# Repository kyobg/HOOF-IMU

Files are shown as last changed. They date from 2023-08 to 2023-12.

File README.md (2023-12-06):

# Hoof-IMU Motion Analysis - Senior Design Project

**Preface:** Here are a couple links to help familiarize yourself with Git and GitHub.

Links: 

(1) How to use Git click [here](https://youtu.be/USjZcfj8yxE?si=m7MtrsjsvbkFWDZs)  

(2) How to use GitHub click [here](https://www.youtube.com/watch?v=nhNq2kIvi9s&ab_channel=ColtSteele)

## Terminology:

**IMU** - Inertial Measurement Unit

**DOF** - Degrees of Freedom

**Laminitis** - The inflammation of the laminae of the foot, which results in extreme pain and instability in horses.

## Project Synopsis:
A custom 9-DOF IMU with an additional 3-axis high-g accelerometer, which is used for impulses where the low-g accelerometer may clip, will be used to detect laminitis or rotational hoof sickness, in racehorses.
The IMUs come equipped with a 3-axis low-g accelerometer, 3-axis high-g accelerometer, 3-axis gyroscope, and 3-axis magnetometer. Additionally, circuitry will be added for other features like GPS, Real-time timekeeping, and power management.

The IMUs will communicate directly to a central hub through a BLE mesh, which will allow wireless transmission of recorded data from each unique IMU device. After data collection, the data will be read from the central into a serial port on a computer where it will save the data and provide a real-time plot for data processing later.

## Goals:
- [x]  Test with mobile battery pack                                                      
- [x]  Add Timestamp to periphal data packet                                              
- [x]  Distance/Reliablility measurement                                                  ~40 ft
- [x]  Complete power management system                                                   
- [x]  Complete real-time plotting using BetterSerialMonitor                              
- [ ]  Integrate GPS into the IMU system                                                  No Longer Feasbile due to Time Constraints
- [ ]  Complete PCB design with integrated circuits and order appropriate chips           Future Goal

## Current Repository Maintainer and Authors
Kyle G:
- [GitHub](https://github.com/kyobg)
- [LinkedIn](https://www.linkedin.com/in/kyle-b-garcia/)

Kevin B:
- [GitHub](https://github.com/kevinbrannan)
- [LinkedIn](https://www.linkedin.com/in/kevin-brannan-885446233/)

Elena M:
- [GitHub](https://github.com/evolutis101)
- [LinkedIn](https://www.linkedin.com/in/elenammontalvo/)

Jonathan H:
- [GitHub](https://github.com/Grlee316)
- [LinkedIn](https://www.linkedin.com/in/jhanbali/)

## Future Repository Maintainer
Josue D:
- [Github](https://github.com/Jdiazcaminos)
- [LinkedIn](https://www.linkedin.com/in/josuediaz-caminos/)

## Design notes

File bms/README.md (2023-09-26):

# Battery Management system
Battery Management System is a critical component in modern battery-powered systems, playing a vital role in maximizing battery lifespan, performance, and safety while also enabling efficient energy management.
## Important factors to consider for BMS 
- Voltage Monitoring
- Current Monitoring
- Temperature Monitoring
- Cell Balancing
- State of Charge (SOC) Estimation
- State of Health (SOH) Estimation
- Overcurrent and Overvoltage Protection
- Cell Protection

## Proportional Integral Derivative (PID)
PID of battery

## Battery we are using 
*Voltage = 3.7 v 
*capacity = 650mAh 
*capacity = 1500mAh
An individual LiPo cell has a nominal voltage of 3.7V. When fully charged you will see nearly 4.3V on the cell but it will quickly drop to 3.7V under normal use. When depleted, the cell will be around 3V. This means your project will need to handle various voltages if you are running directly from a cell.
voltage chart

## Theoretical components 


## Monitoring test  ( using SparkFun battery babysitter) 




## Monitoring test 2 ( using IN219) 
Measure_PCV_IN219

## Resource

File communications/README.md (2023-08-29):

# Communications

This folder contains the code of both the peripheral/server devices and the central/client device.

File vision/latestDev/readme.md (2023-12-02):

This folder will contain the latest development of this vision projects

Current MATLAB Project file is [latest](../../vision/latestDev/horse_test3.m)

Current Masking file is: [mask](../../vision/latestDev/createMask6.m)

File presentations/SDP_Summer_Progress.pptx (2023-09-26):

## Hoof IMU

By
Elena Montalvo
Jonathan Hanbali
Josue Diaz
Kevin Brannan
Kyle Garcia
Matthew Wagaman

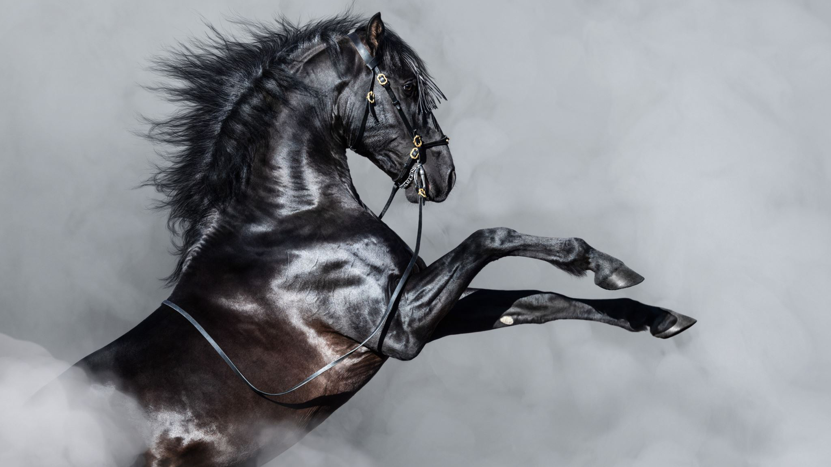
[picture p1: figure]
Black horse rearing in smoke

## Data Saving and Post Processing

- KST proved to not be capable of plotting the data in real-time using .csv files. As a result, BetterSerialPlotter is being used to plot data real-time, and is capable of exporting the results as a .csv file afterwards for post-processing.
- Alternatively, a Python script may be utilized for sorting data per device and exporting each to their own .csv file for individual device processing.

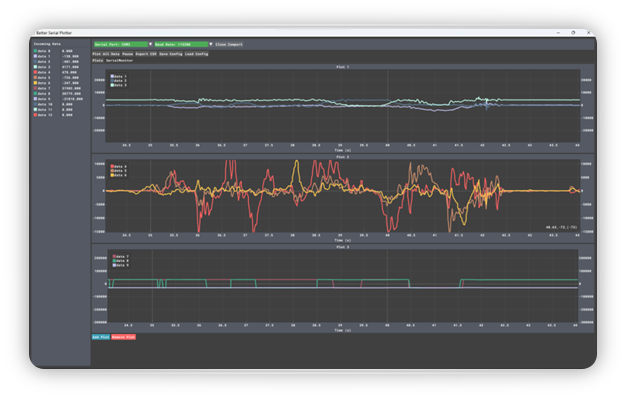
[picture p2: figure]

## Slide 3

Important factors to consider for BMS

Voltage Monitoring
Current Monitoring
Temperature Monitoring
Cell Balancing
State of Charge (SOC) Estimation
State of Health (SOH) Estimation
Overcurrent and Overvoltage Protection
Cell Protection

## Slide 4

Proportional Integral Derivative (PID)

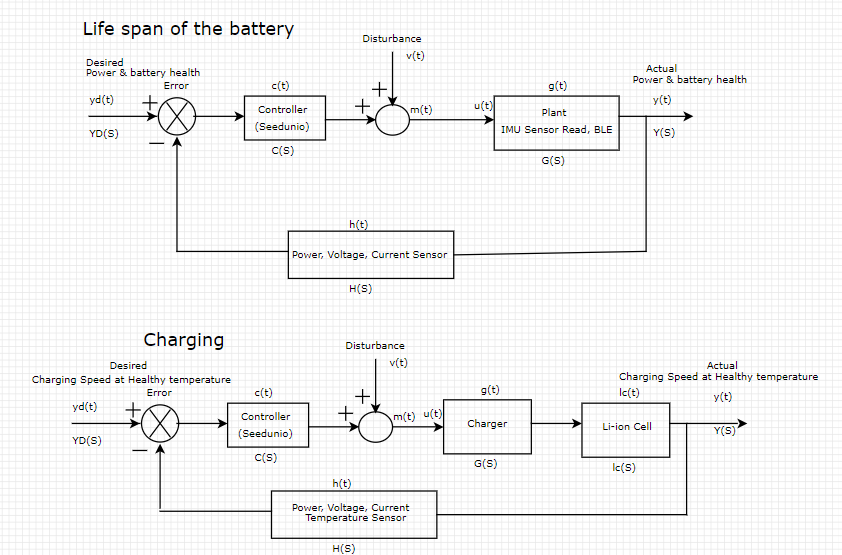
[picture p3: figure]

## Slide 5

BATERRY

Voltage = 3.7 v capacity = 650mAh capacity = 1500mAh An individual LiPo cell has a nominal voltage of 3.7V. When fully charged you will see nearly 4.3V on the cell but it will quickly drop to 3.7V under normal use. When depleted, the cell will be around 3V. This means your project will need to handle various voltages if you are running directly from a cell

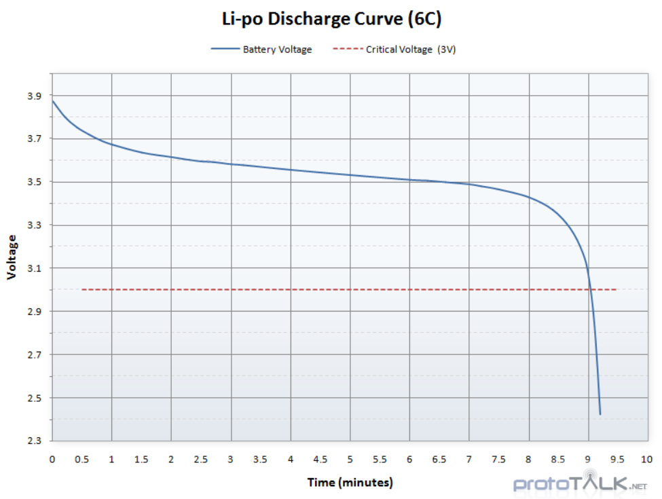
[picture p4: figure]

## Hardware to for BMS

- The Battery Babysitter features a pair of Texas Instruments LiPo-management ICs: a BQ24075 battery charger and a BQ27441-G1A fuel gauge.
- INA219 High Side DC Current Sensor Breakout - 26V ±3.2A Max - STEMMA QT

## Computer Vision

By using machine learning, we're aiming to create a skeletal body over a recorded video of the horse movement
Currently exploring options on using already build libraries and models to help us in detecting the skeleton and movements

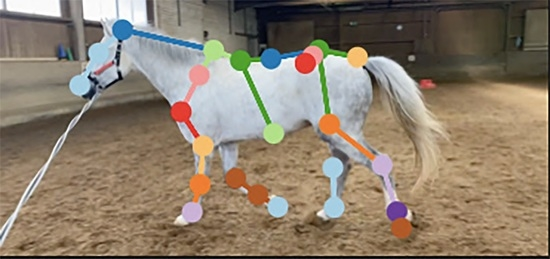
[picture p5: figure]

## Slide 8

Questions?

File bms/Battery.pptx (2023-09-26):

## BATTERY

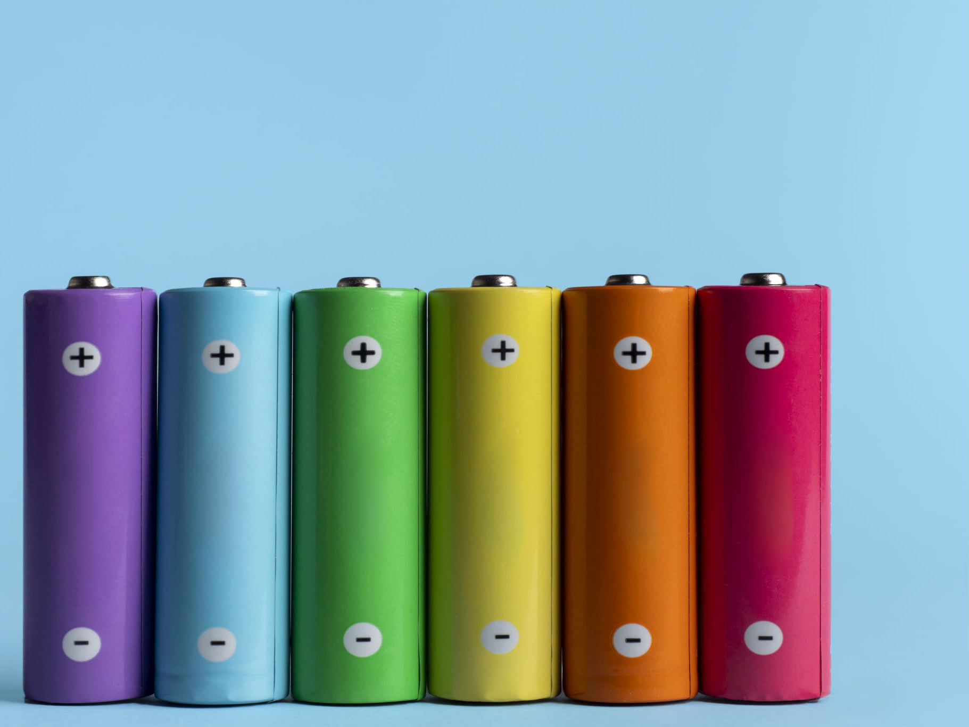
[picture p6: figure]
Multi-colour batteries

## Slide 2

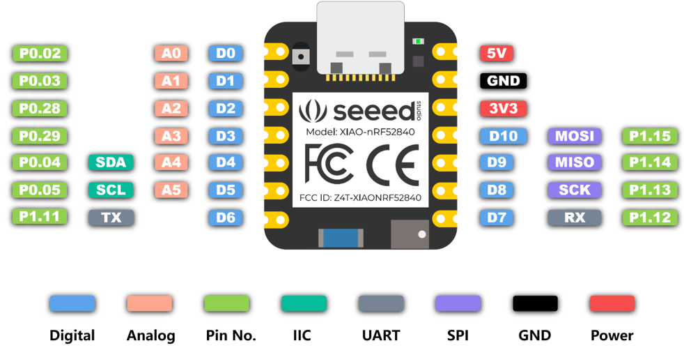
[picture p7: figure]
pir
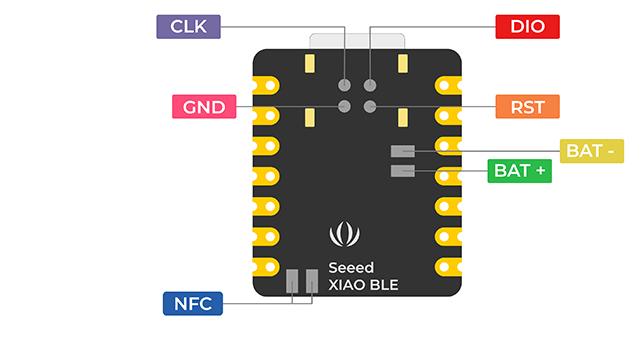
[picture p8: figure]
pir

## POWER MANAGEMENT UNIT (PMU)

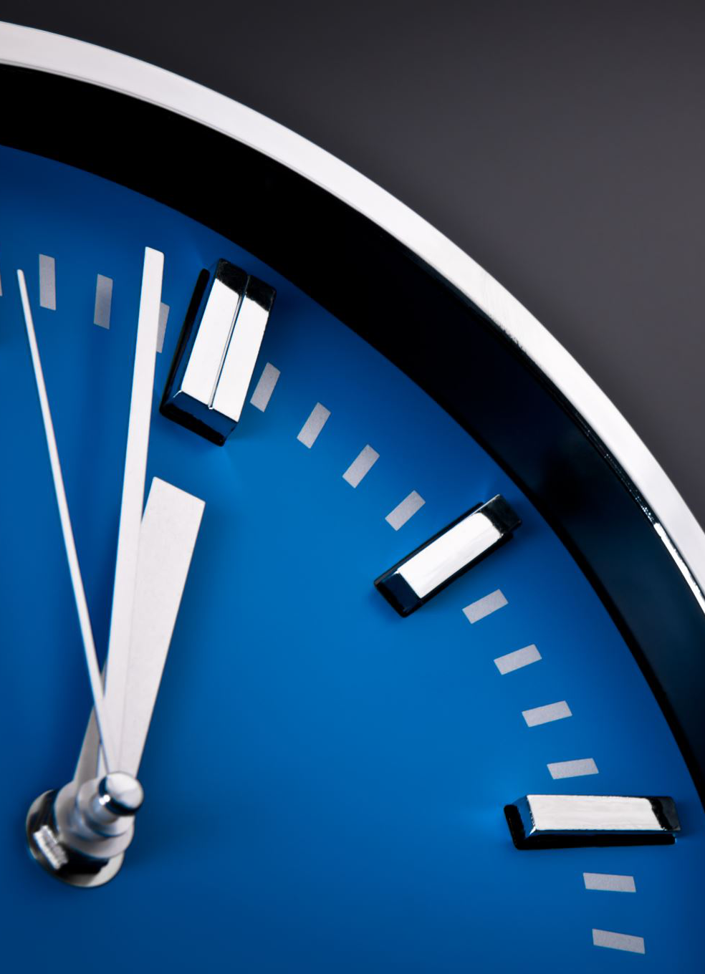
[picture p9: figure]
A blue wall clock showing the time 11:59

- The PMU automatically detects which power and clock resources are required by the different components in the system at any given time. It will then start/stop and choose operation modes in supply regulators and clock sources, without user interaction, to achieve the lowest power consumption possible.

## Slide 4

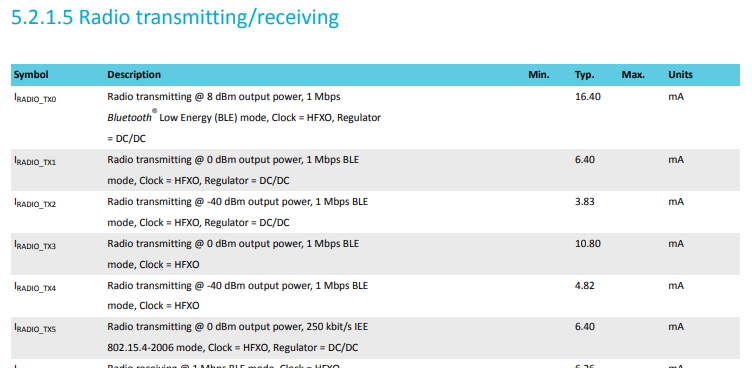
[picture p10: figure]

## POWER REQUIREMENT & CONSUMPTION

Seeed Studio XIAO nRF52840 (Sense) | | ISM330DHCX | MMC5983MA | MicroSD card breakout board+ | H3LIS331DL
Voltage | Current | Current | Current | Current | Current
3.3v | 50mA or 100mA | 1.5mA | 50mA or 100mA | 150mA | 7 μA

Total | ~351.5mA

## POWER REQUIREMENTS

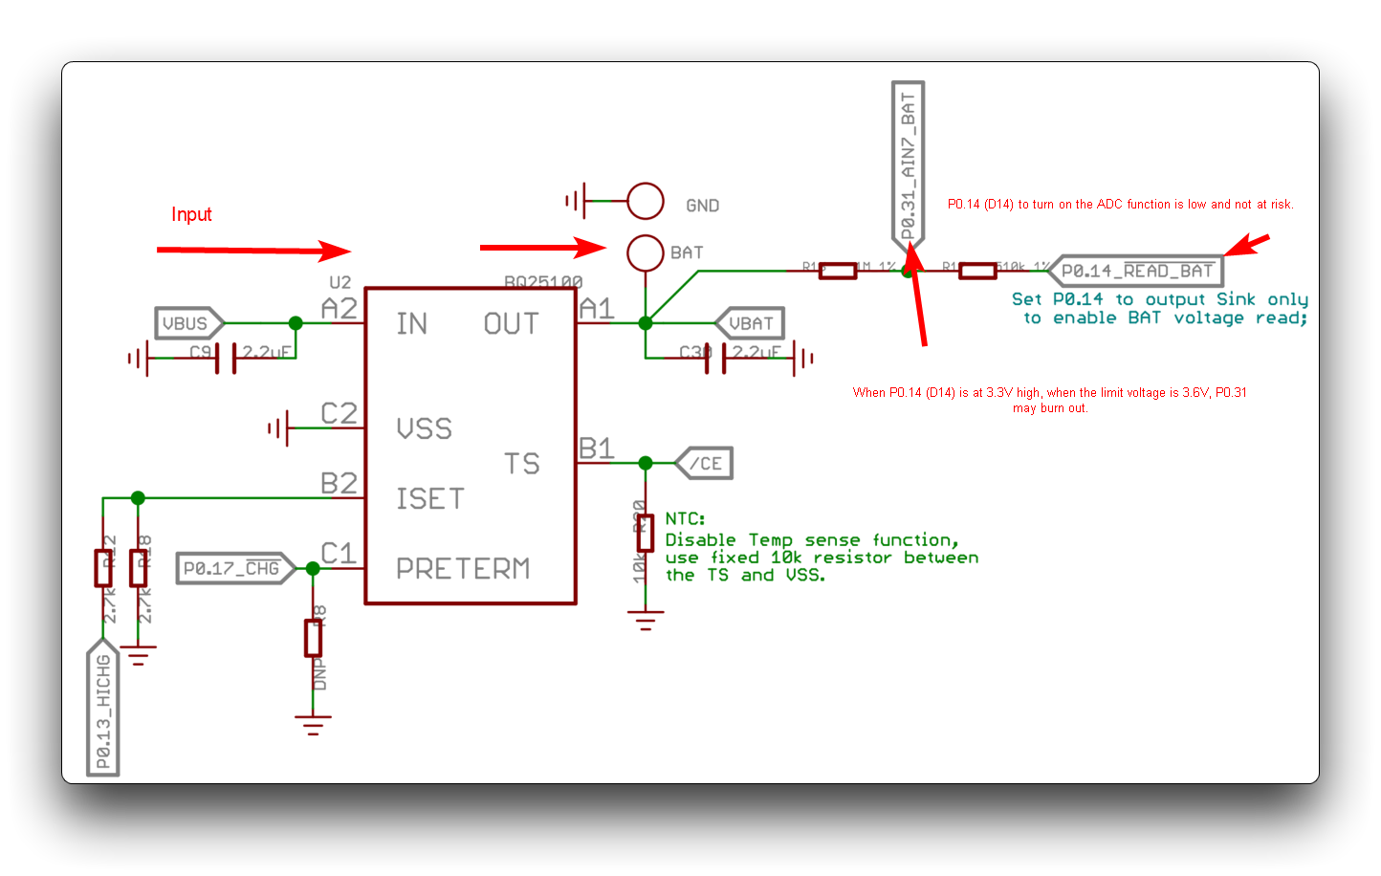
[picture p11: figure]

When P0.14 (D14) turns off the ADC function at a high level of 3.3V, P0.31 will be at the input voltage limit of 3.6V. There is a risk of burning out the P0.31 pin.

## Battery babysitter

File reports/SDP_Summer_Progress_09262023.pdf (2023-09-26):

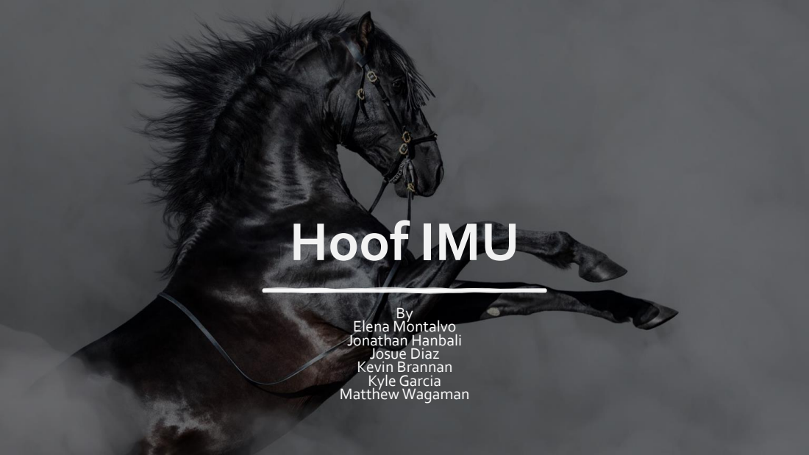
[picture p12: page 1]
Hoof IMU; By Elena Montalvo Jonathan Hanbali Josue Diaz Kevin Brannan Kyle Garcia Matthew Wagaman

# Data Saving and Post Processing

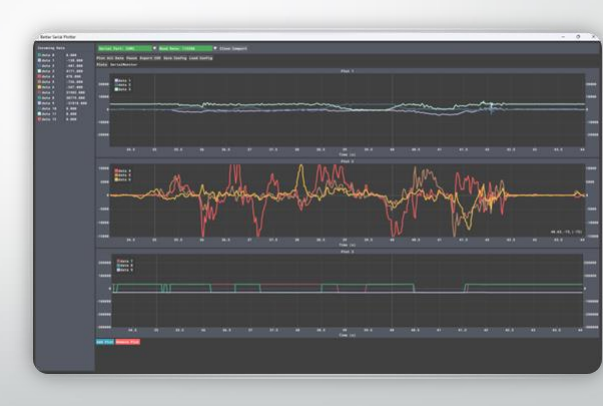
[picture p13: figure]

- KST proved to not be capable of plotting the data in real-time using .csv files. As a result, BetterSerialPlotter is being used to plot data real-time, and is capable
of exporting the results as a .csv
file afterwards for post-processing.
- Alternatively, a Python script may
be utilized for sorting data per device and exporting each to their own .csv file for individual device processing.

# IMPORTANT FACTORS TO CONSIDER FOR BMS

Voltage Monitoring

Current Monitoring

Temperature Monitoring

Cell Balancing

State of Charge (SOC) Estimation

State of Health (SOH) Estimation

Overcurrent and Overvoltage Protection

Cell Protection

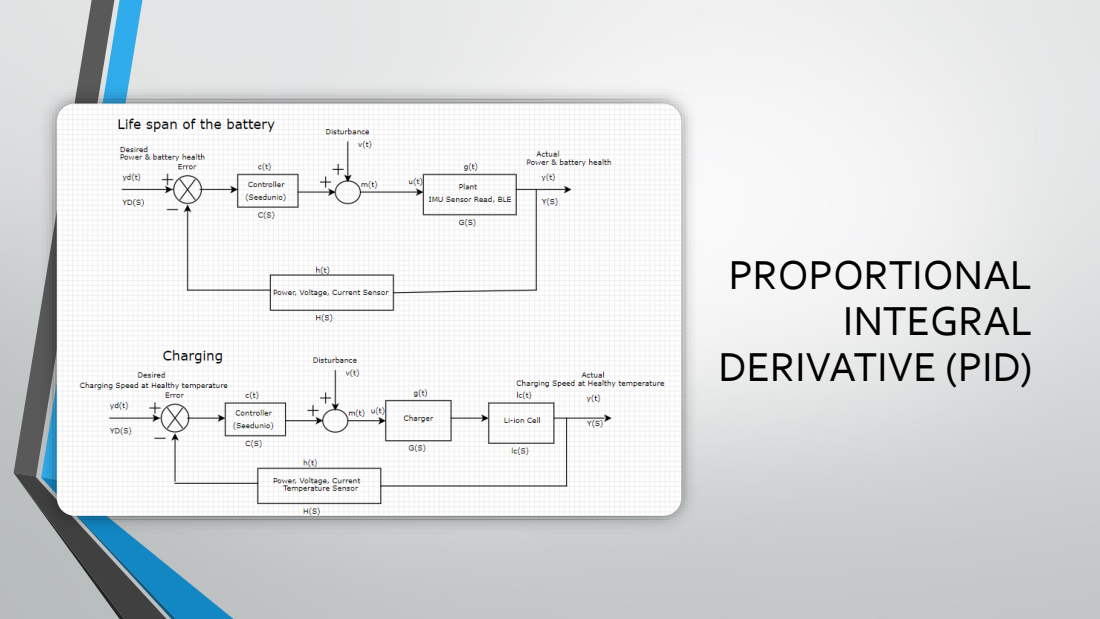
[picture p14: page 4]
PROPORTIONAL INTEGRAL DERIVATIVE (PID)

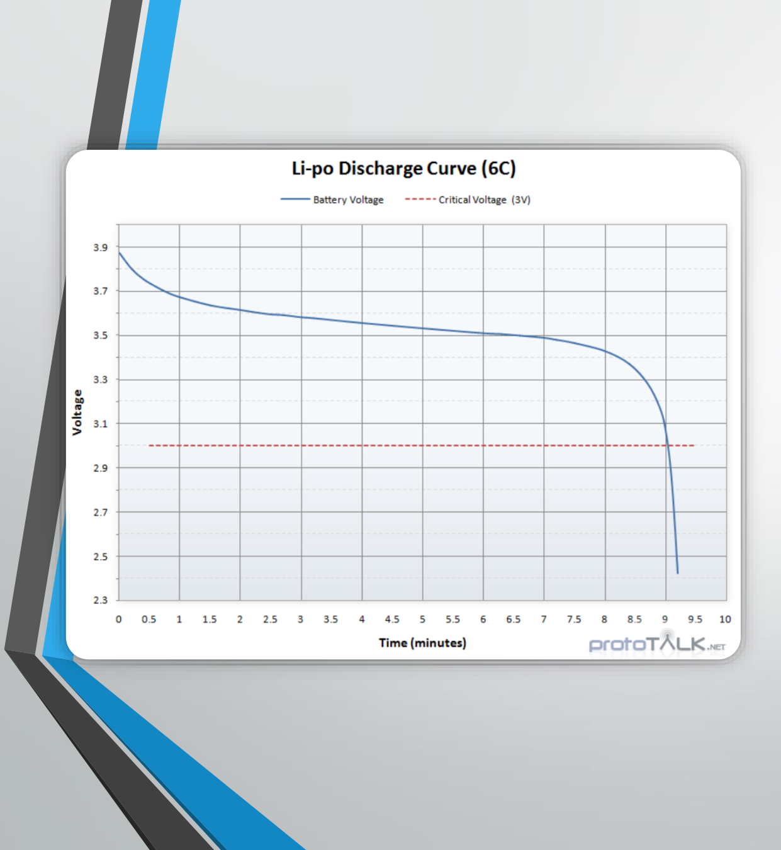
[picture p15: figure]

# BATERRY

- Voltage = 3.7 v capacity = 650mAh capacity = 1500mAh An individual LiPo cell has a nominal voltage of 3.7V. When fully charged you will see nearly 4.3V on the cell but it will quickly drop to 3.7V under normal use. When depleted, the cell will be around 3V. This means your project will need to handle various voltages if you are running directly from a cell

# Hardware to for BMS

## - The Battery Babysitter features a pair of Texas Instruments LiPomanagement ICs: a BQ24075 battery charger and a BQ27441-G1A fuel

gauge.

### - INA219 High Side DC Current Sensor Breakout - 26V ±3.2A Max - STEMMA QT

# Computer Vision

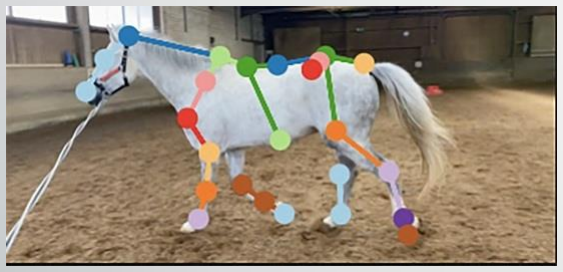
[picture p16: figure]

## - By using machine learning, we're aiming to create a skeletal body over a recorded video of the horse movement - Currently exploring options on using already build libraries and models to help us in detecting the skeleton and movements

# Questions?

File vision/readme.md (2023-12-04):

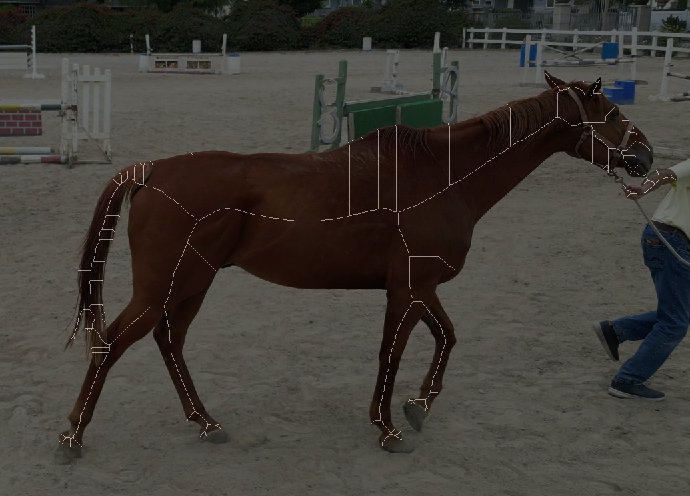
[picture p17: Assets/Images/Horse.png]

# This Section of the Repository is for the IMU PROJECT - Vision section

This Repo will contains the development of the Computer Vision Aspect of this project

We created mask using the color thresholder application on MATLAB. We took a screenshoot from the video given and then use the application in MATLAB to create a mask. After the creation of the mask, we then apply the mask to the video by processing the video frame by frame. By doing so we processing an "image" such that we could apply these masks. 

**Creating Mask:**
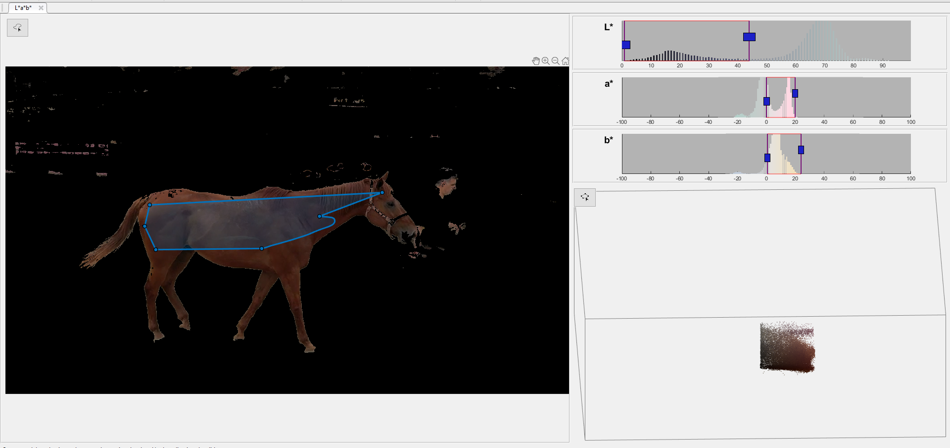
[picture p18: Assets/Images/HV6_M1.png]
mask6


After applying the mask created, we then use the blob analysis as pictured below. 

**Before Blob Analysis:**
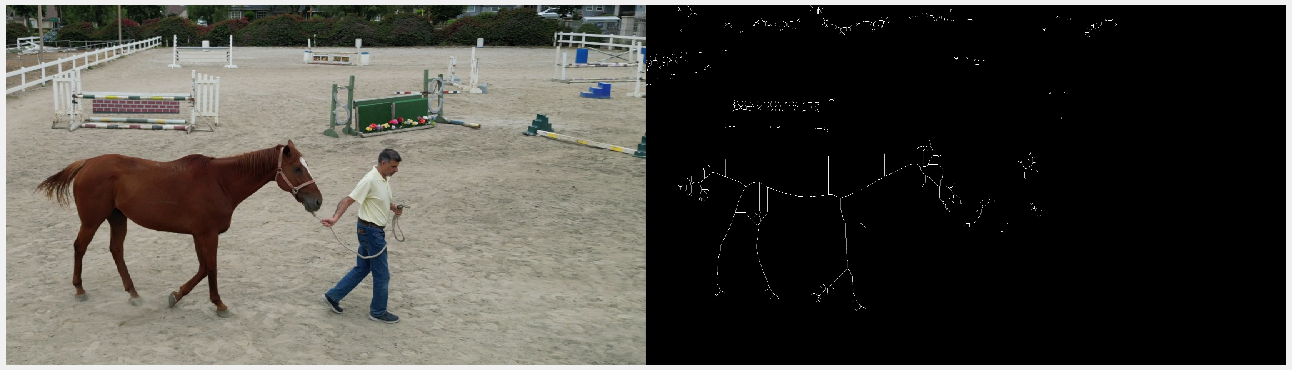
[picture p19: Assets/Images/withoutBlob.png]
WithoutBlob


**After Blob Analysis:**
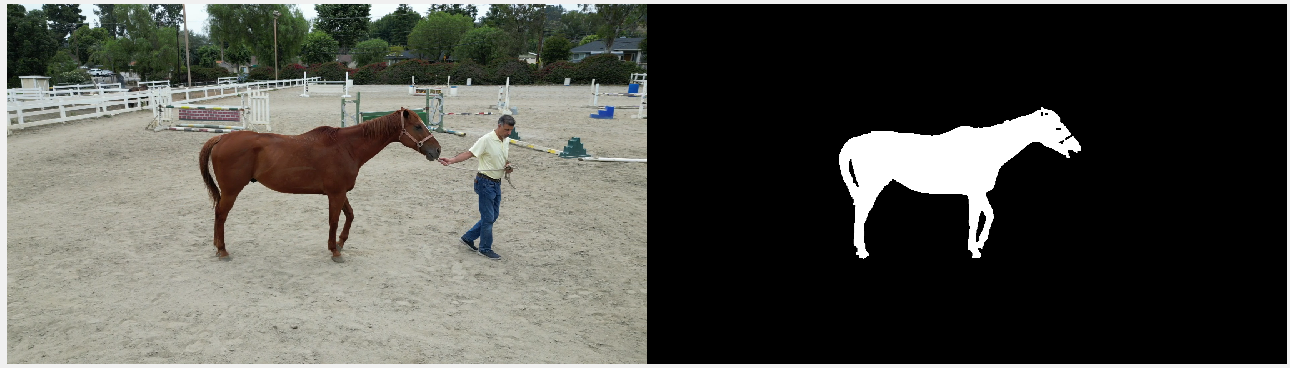
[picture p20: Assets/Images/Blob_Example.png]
Blob

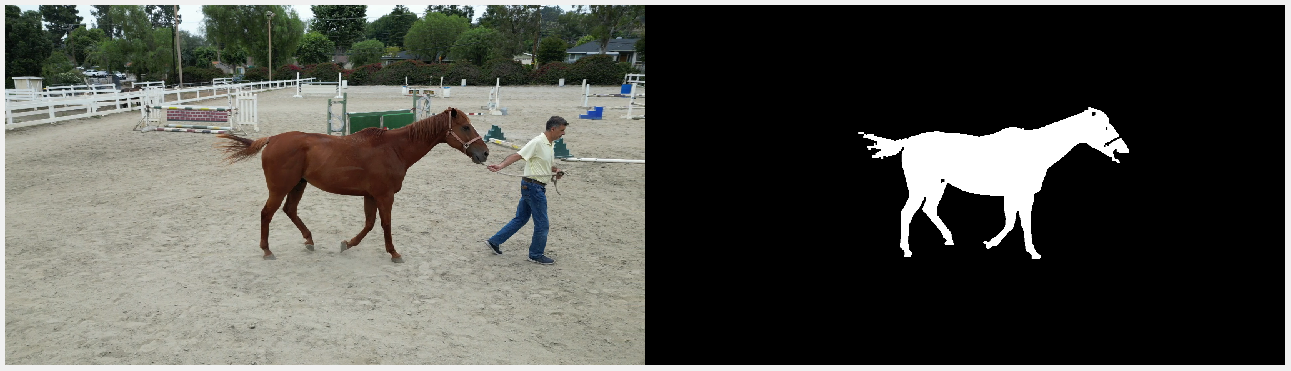
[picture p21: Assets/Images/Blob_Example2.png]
Blob2


Notice that before the blob analysis, we encounter a lot of noise, since the color difference method is not perfect in essence (it will also read some other colors that the image/video contains, so not everything is isolated). The blob analysis will analyze the image/video and will eliminate "smaller blobs", such that we have an isolated image of the bigger blobs since we tailored our color masking to the color of the horse itself. 

**Overlaying largest blob to our image / video frame:**
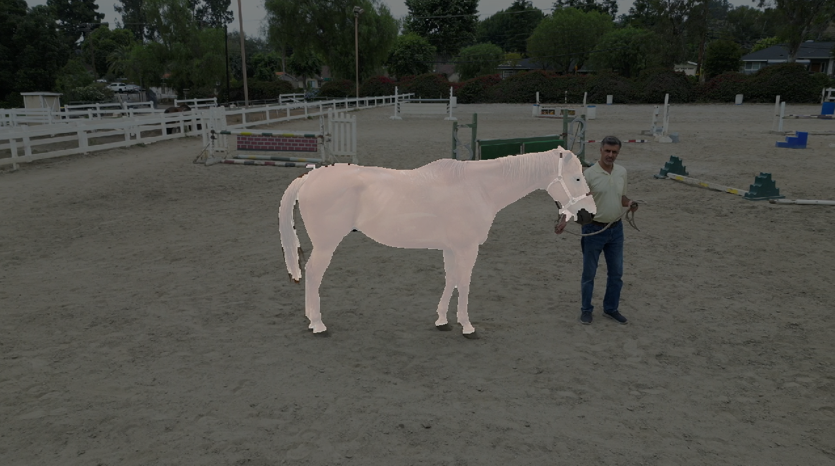
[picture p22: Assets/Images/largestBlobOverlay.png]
OverlayedBlob


when then uses the skel feature of bwmorph matlab function to get the "skeleton":**
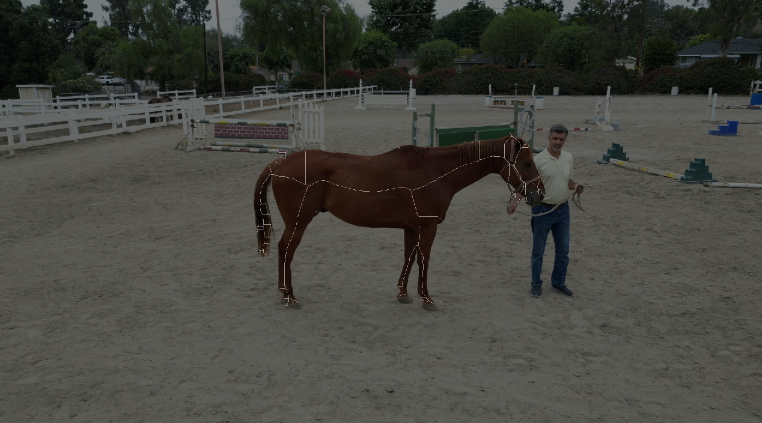
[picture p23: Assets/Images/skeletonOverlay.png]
skeletonOverlay


**Our current progress is located at:**
[Horse 3](../vision/latestDev/horse_test3.m)

Current Mask:
[Mask 6](../vision/latestDev/createMask6.m)

### For more information of the MATLAB functions that are being used, please check the links below
================================================================

Information in regards of the MATLAB function being used for this project, their brief description, and help link to matlab help in alphabetical order:

- [bwlabel](https://www.mathworks.com/help/images/ref/bwlabel.html) - Label connected components in 2-D binary image
- [bwmorph](https://www.mathworks.com/help/images/ref/bwmorph.html) - Morphological operations on binary image
- [close](https://www.mathworks.com/help/matlab/ref/videowriter.close.html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) - Close file / figures
- [hasFrame](https://www.mathworks.com/help/matlab/ref/videoreader.hasframe.html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) - Determine if video frame is available to read
- [im2uint8](https://www.mathworks.com/help/images/ref/im2uint8.html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) - Convert image to 8-bit unsigned integers
- [imclose](https://www.mathworks.com/help/images/ref/imclose.html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) - Morphologically close image
- [imopen](https://www.mathworks.com/help/images/ref/imopen.html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) - Morphologically open image
- [imshowpair](https://www.mathworks.com/help/images/ref/imshowpair.html?s_tid=doc_ta) - Compare differences between images
- [ismember](https://www.mathworks.com/help/matlab/ref/double.ismember.html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) - Array elements that are members of set array
- [max](https://www.mathworks.com/help/matlab/ref/max.html?searchHighlight=max&s_tid=srchtitle_support_results_1_max) - Maximum element of array
- [open](https://www.mathworks.com/help/matlab/ref/videowriter.open.html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) - Open file for writing video data
- [pause](https://www.mathworks.com/help/matlab/ref/pause.html?s_tid=doc_ta) - Stop MATLAB execution temporaily
- [readFrame](https://www.mathworks.com/help/matlab/ref/videoreader.readframe.html?s_tid=doc_ta) - Read next video frame
- [regionprops](https://www.mathworks.com/help/images/ref/regionprops.html?s_tid=doc_ta) - Measure properties of image regions
- [strel](https://www.mathworks.com/help/images/ref/strel.html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) - Morphological structuring element; essential part of morphological dilation and erosion operation
- [writevideo](https://www.mathworks.com/help/matlab/ref/videowriter.writevideo.html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) - Write video data to file
- [VideoReader](https://www.mathworks.com/help/matlab/ref/videoreader.html?s_tid=doc_ta) - Create an object to read video files
- [VideoWriter](https://www.mathworks.com/help/matlab/ref/videowriter.html?s_tid=doc_ta) - Create an object to write video files

================================================================

- [Morphological Operations](https://www.mathworks.com/help/images/morphological-filtering.html)

Morphology is a broad set of image processing operations that process images based on shapes. In a morphological operation, each pixel in the image is adjusted based on the value of other pixels in its neighborhood. By choosing the size and shape of the neighborhood, you can construct a morphological operation that is sensitive to specific shapes in the input image.

================================================================

### Improvements and Targets:
**Done:**\
[&check;] Better color masking\
[&check;] Blob Analysis to minimize other objects\

**Failed:**\
[&cross;] Minimize the missing hoof masking (less mask perhaps)\
❗**Reason:** We tried to apply different masks from the other videos that we have, but seems like the best mask is the mask from video6, hence we called the mask createMask6.

[&cross;] Cleaner skeleton with only main line showings\
❗**Reason:** We tried to clean the middle section of the skeleton so it will only contain "longer" lines, but apparently the center lines consisted of dashed lines, such that it will be impossible to create one long lines. I tried a different method to create longer lines (to combine the lines in the torso part of the horse) and it created a wrong output (undesired result).

**Ongoing:**\
[&emsp;] Overlay the skeleton with lines to have a thicker and better skeletons\
[&emsp;] Writing the video output as a file for ease of use

================================================================

### Notes:
- This project is based on [Image Processing Toolbox](https://www.mathworks.com/products/image.html) on MATLAB. In order to make this project to work properly, you would need to download the Image Processing Toolbox from MATLAB and install it on your computer.

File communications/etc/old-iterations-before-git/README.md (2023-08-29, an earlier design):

This folder contains old revisions of the devices prior to the regular updating of the GitHub versions found one directory up.

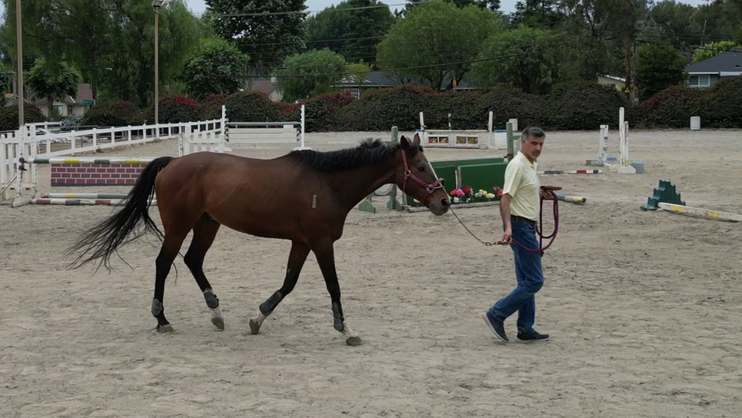
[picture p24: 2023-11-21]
vision/Horse Pictures/HV10-1.png

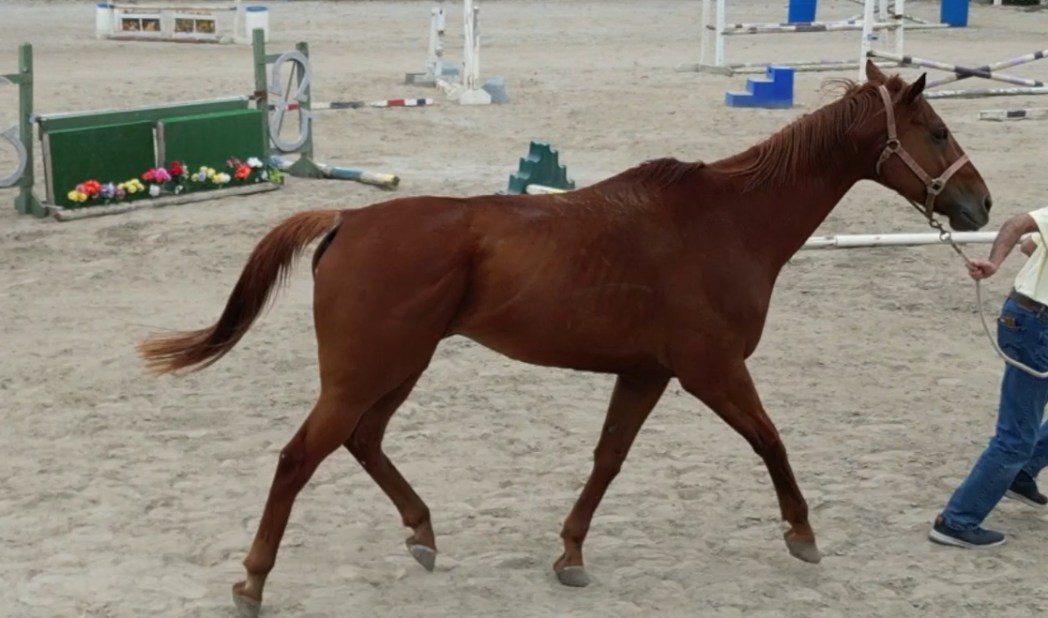
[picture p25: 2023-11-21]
vision/Horse Pictures/HV6-1s.png

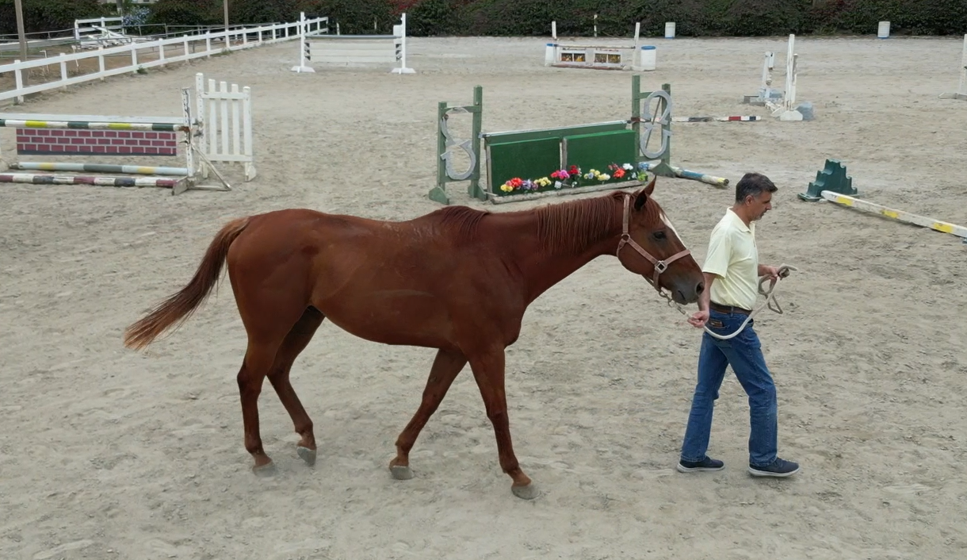
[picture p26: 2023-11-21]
vision/Horse Pictures/HV1-1s.png

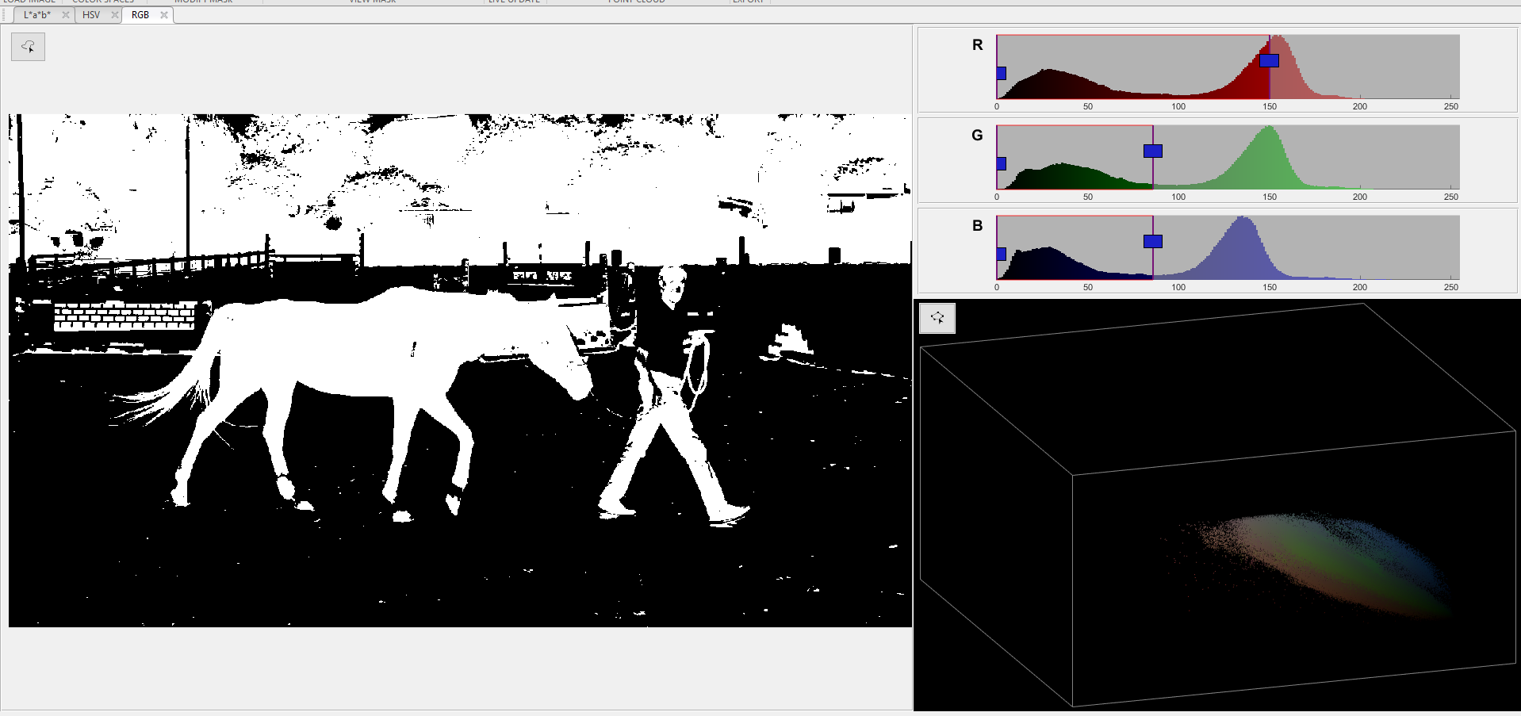
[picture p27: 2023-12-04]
vision/Masks/HV10_M1_RGB_Binary.png

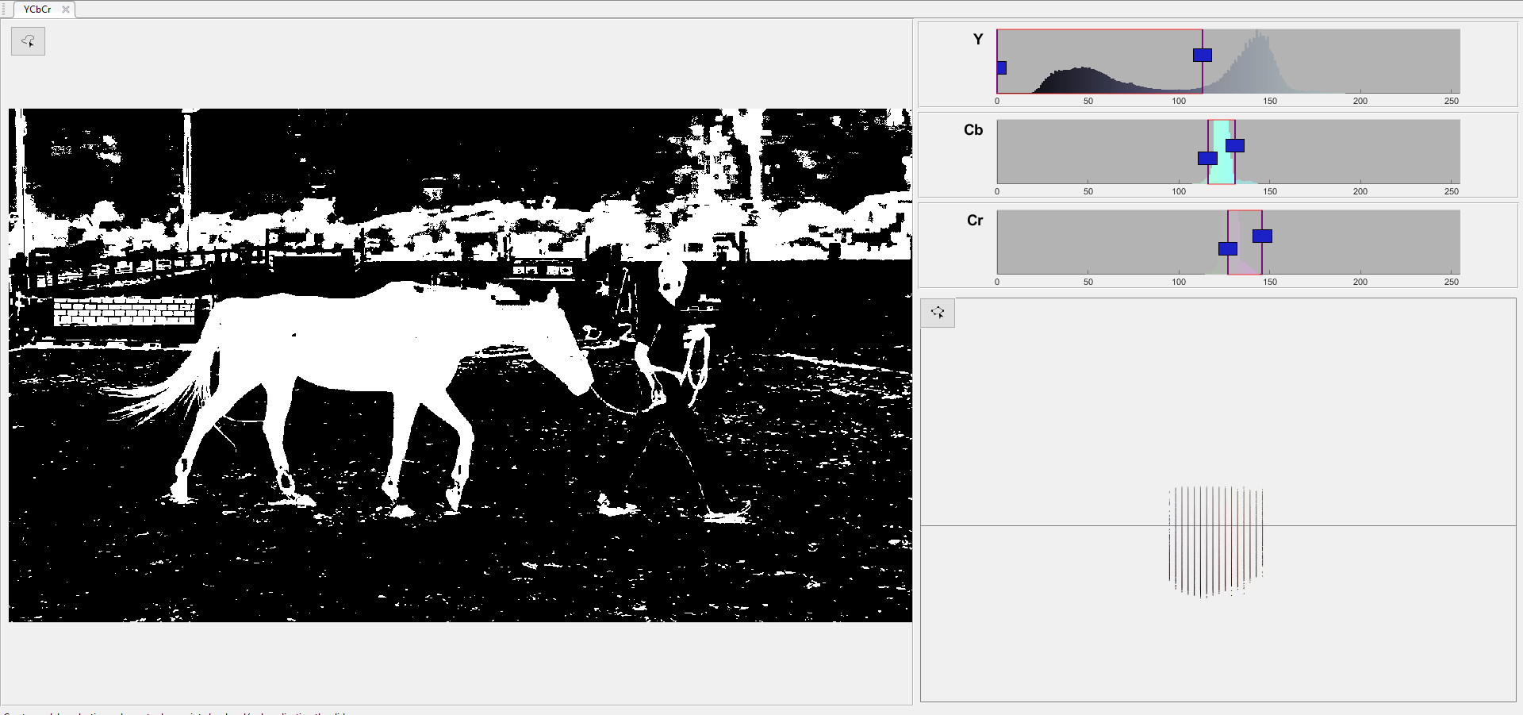
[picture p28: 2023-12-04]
vision/Masks/HV10_M4_YCbCr_Binary.png

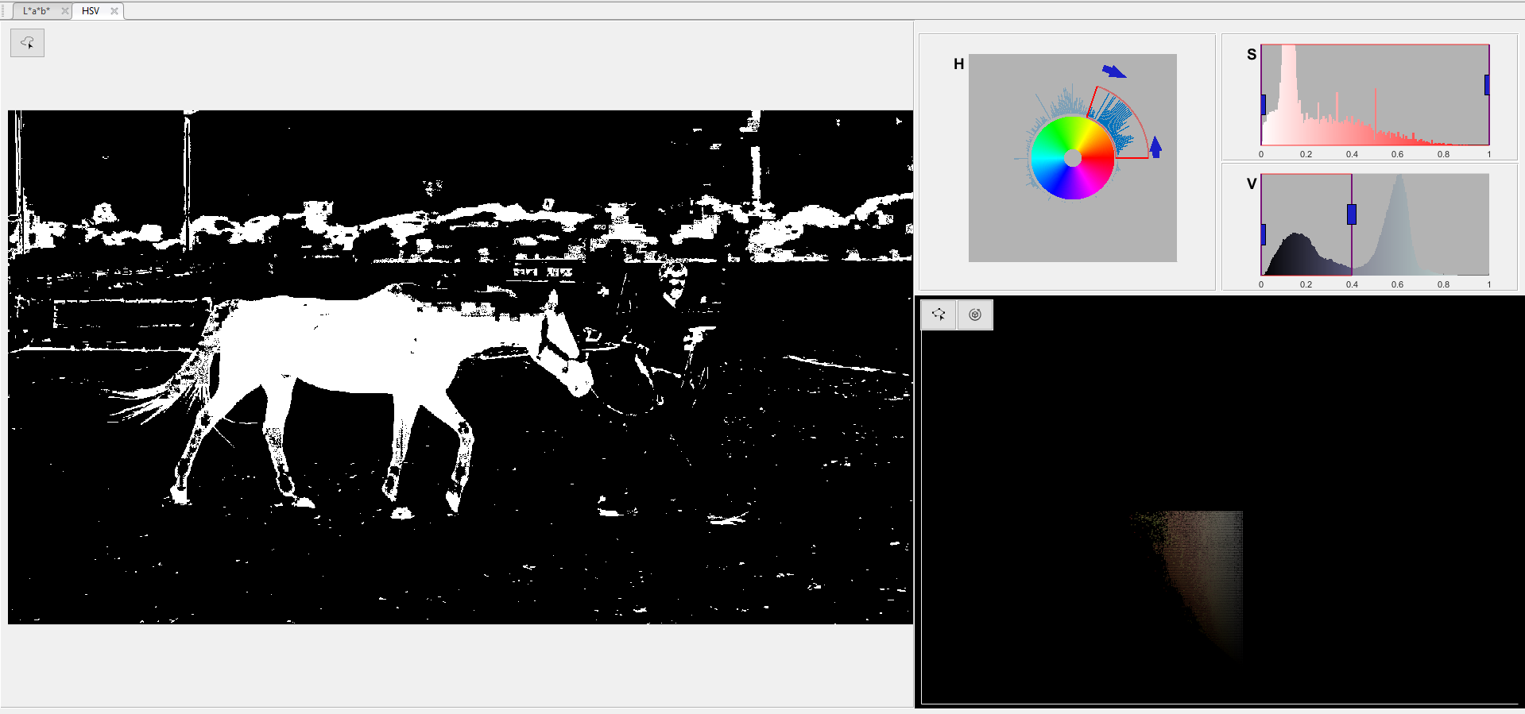
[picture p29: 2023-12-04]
vision/Masks/HV10_M2_HSV_Binary.png

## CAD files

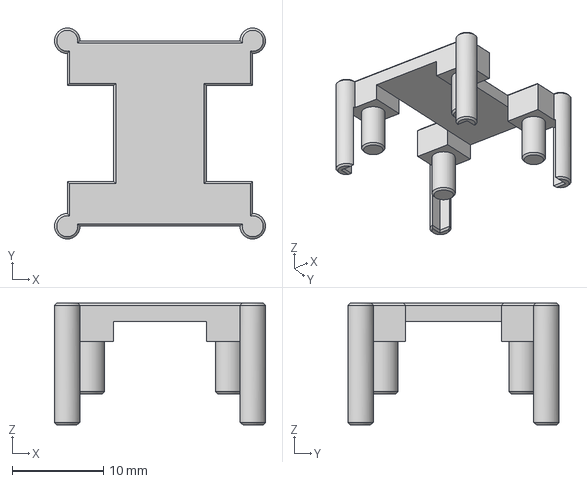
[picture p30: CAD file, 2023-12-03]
cad/printable_files/V2/Accelerometer_Press_Plate.step
23.1 x 23.1 x 13.3 mm

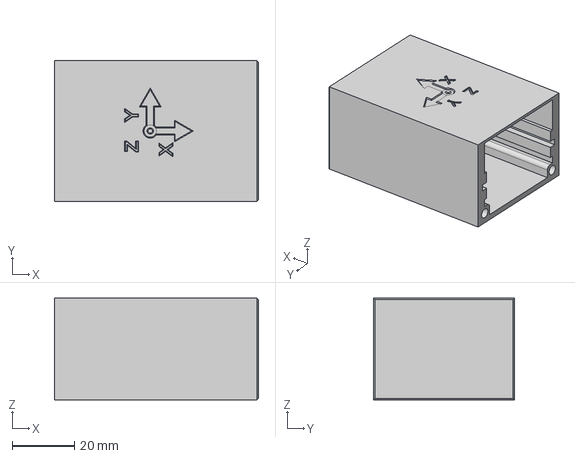
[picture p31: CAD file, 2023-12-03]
cad/printable_files/V2/Electronics_Shell.step
65.4 x 45.2 x 32.6 mm

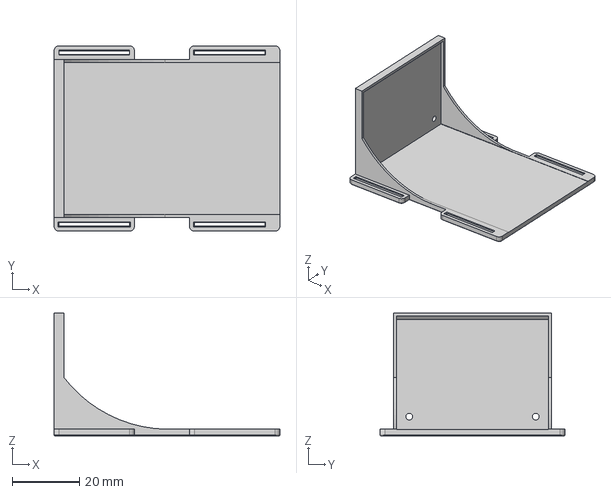
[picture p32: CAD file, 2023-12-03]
cad/printable_files/V2/Shell_Mount.step
67.4 x 55.2 x 36.6 mm

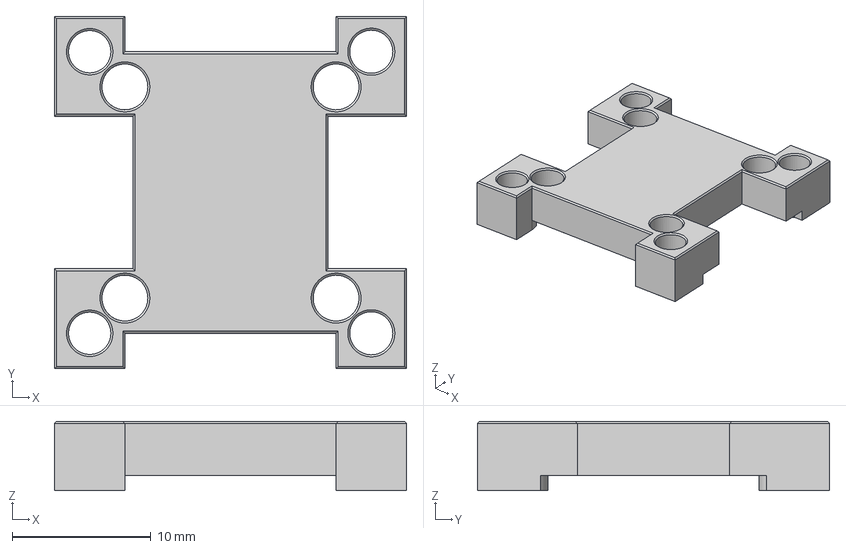
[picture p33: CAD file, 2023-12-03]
cad/printable_files/V2/IMU_Press_Plate.step
25.4 x 25.4 x 5.00 mm

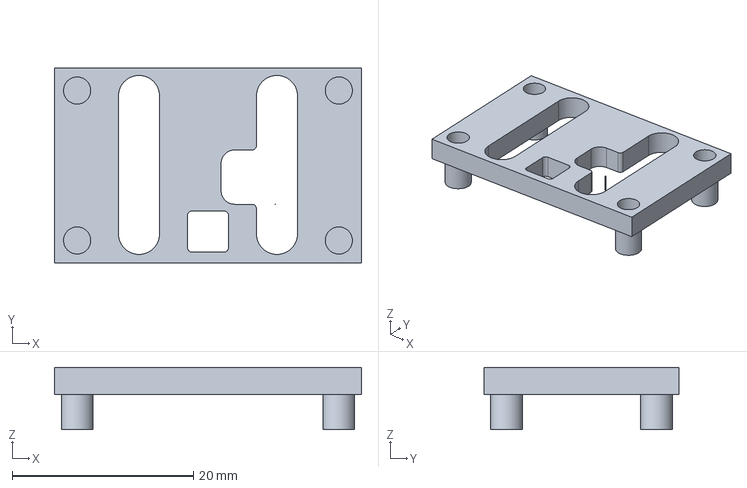
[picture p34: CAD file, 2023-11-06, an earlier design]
cad/printable_files/V1/Seeed Plate.step
33.9 x 21.6 x 6.90 mm

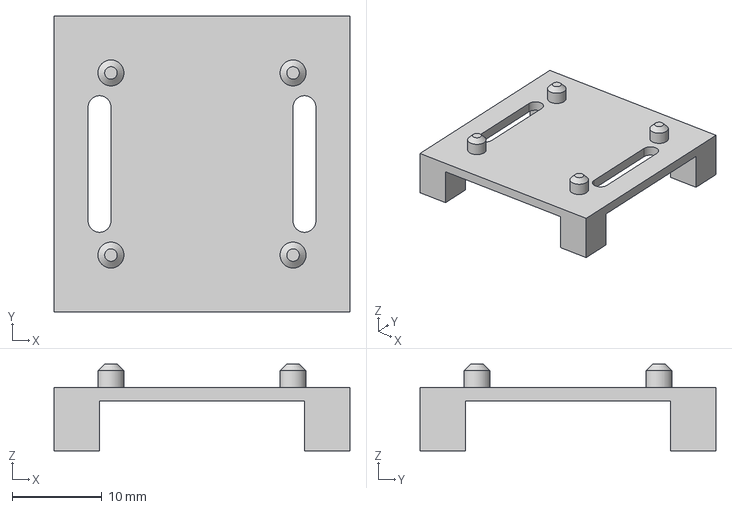
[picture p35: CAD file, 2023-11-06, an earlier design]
cad/printable_files/V1/IMU_Holder.step
33.0 x 33.0 x 9.70 mm

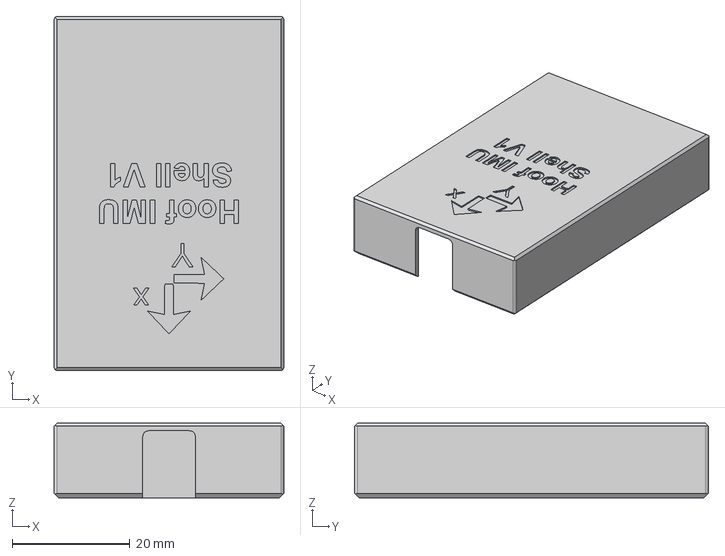
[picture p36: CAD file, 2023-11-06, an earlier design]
cad/printable_files/V1/Slide On Lid.step
39.0 x 60.2 x 12.7 mm

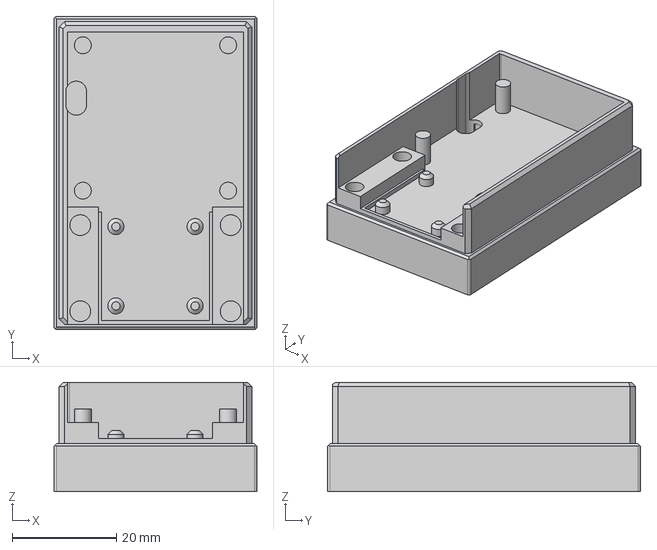
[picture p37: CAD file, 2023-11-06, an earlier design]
cad/printable_files/V1/BMS Battery Holder.step
39.0 x 60.2 x 21.0 mm

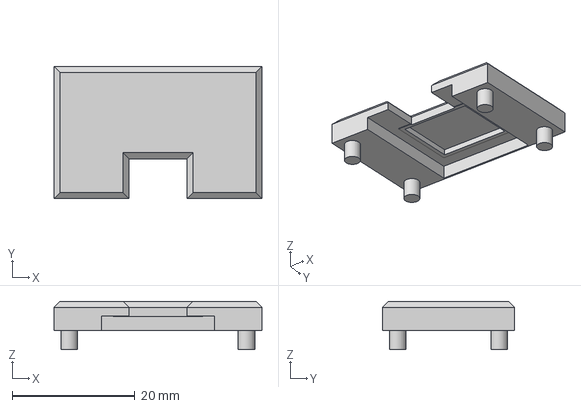
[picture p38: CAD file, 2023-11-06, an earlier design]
cad/printable_files/V1/Seeed Compression Plate.step
33.9 x 21.6 x 7.90 mm

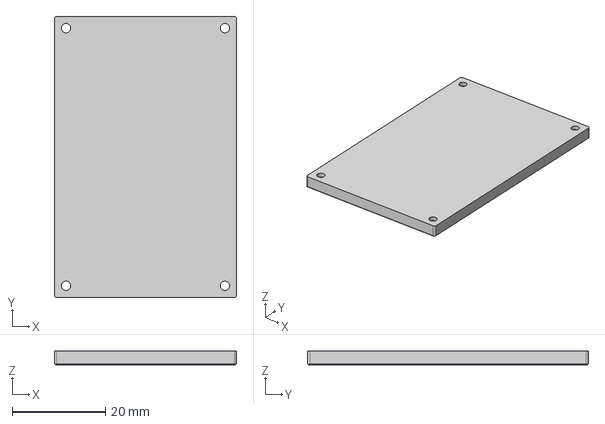
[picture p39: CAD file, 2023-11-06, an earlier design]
cad/printable_files/V1/Bottom Plate.step
39.0 x 60.2 x 3.00 mm

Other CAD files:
cad/SDP_IMU_HOLDER v4.f3d

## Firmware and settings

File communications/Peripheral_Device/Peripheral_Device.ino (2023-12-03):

  /*
 * Kevin Brannan
 * Kyle Garcia
  Combined Funcitonality:
  Data Rate (DR) Interrupt
  Filters
  High Speed I2C
  Raw Data, No Conversions
*/

#include <Wire.h>
#include "src/SparkFun_ISM330DHCX.h"                        // 6 Degree-of-Freedom (6DOF) Accel + Gyro Library
#include "src/SparkFun_MMC5983MA_Arduino_Library.h"         // Magnetometer Library
#include "src/SparkFun_LIS331.h"                            // 3-Axis High G Accelerometer Library
#include "src/SparkFunBQ27441.h"                            // Battery Management System Library

//For Bluetooth Low Energy (BLE):
#include <bluefruit.h>
#include <Adafruit_LittleFS.h>
#include <InternalFileSystem.h>

// BLE Service
BLEDfu  bledfu;  // OTA DFU service
BLEDis  bledis;  // device information
BLEUart bleuart; // uart over ble
BLEBas  blebas;  // battery

/////////////////////////////////////////////////////////////////////
// BMS System
const uint16_t BATTERY_CAPACITY = 650;      //battery capacity in mAh.
const uint16_t TERMINATE_VOLTAGE = 3000;    //lowest operational voltage in mV.
const uint16_t TAPER_CURRENT = 12;          //Control charging rate. this is the lowest value.
const int PERCENTAGE_INTERVAL = 1;
uint32_t lasttime = 0;
#define GPOUT_PIN D2
#define BAS_TIME_INTERVAL 60000 

/////////////////////////////////////////////////////////////////////
//Magnetometer (from sensor hub example)

// 8 bit addressing is required for the 6DoF
// to communicate with its' external sensors.

#define MAG_ADDR_READ 0x61 // (0x30 << 1) | 1)
#define MAG_ADDR_WRITE 0x60 // (0x30 << 1)

#define MAG_READ_REG 0x00 // Read from 0x00
#define MAG_READ_LEN 0x07 // Read seven times consecutively

#define MAG_WRITE_REG 0x09 
#define MAG_WRITE_DATA 0x01 // Value to write to INT_CTRL0 

/////////////////////////////////////////////////////////////////////
//ISM330 Accel + Gyro (6DOF)
#define interrupt_pin D0
#define mag_int_pin   D1

/////////////////////////////////////////////////////////////////////

SparkFun_ISM330DHCX myISM; 
SFE_MMC5983MA myMag; 
LIS331 myLis;

//From standalone lib example
volatile bool newDataAvailable = true;
uint32_t rawValueX = 0; 
uint32_t rawValueY = 0;
uint32_t rawValueZ = 0;

// for high g read
int16_t rawAccelX = 0;
int16_t rawAccelY = 0;
int16_t rawAccelZ = 0;

struct mag_data_t
{
  uint16_t scaledX;
  uint16_t scaledY;
  uint16_t scaledZ;
};

struct accel_high_data_t
{
  uint16_t X;
  uint16_t Y;
  uint16_t Z;  
};

 struct all_data_t
 {  
   char headerMSB;                            // Packet Identifier
   char headerLSB;                            // Packet Identifier
   uint16_t millisecondsMSB;                  // Time High
   uint16_t millisecondsLSB;                  // Time Low
   // Structs for X,Y,Z data
   sfe_ism_raw_data_t   accelData;            // Low-g Accelerometer Raw Data
   sfe_ism_raw_data_t   gyroData;             // Gyroscope Raw Data
   mag_data_t           magData;              // Magnetometer Raw Data
   accel_high_data_t    high_g_data;          // High-g Accelerometer Raw Data
 };
 
const int union_size = sizeof(all_data_t);    // Size of the struct for union

union bitPacket_t{
  all_data_t allData;
  int16_t buf[union_size];                    // The union allocates space equal to the amount of data +  the size of the data as an array of int16_t
};
bitPacket_t data;                             // Union referred to as data from this point on


////////////////////////////////////////////////////////////////

void setup(void)
{
  data.allData.headerMSB = '%';
  data.allData.headerLSB = '%';

  
  pinMode(interrupt_pin, INPUT);

  Serial.begin(115200);   
  Wire.begin();
  Wire.setClock(400000);
  delay(3000);
  myLis.setI2CAddr(0x19);                   // This must be called before .begin()
  myLis.setODR(LIS331::DR_100HZ);                   // Sample at 100 Hz
  myLis.setFullScale(LIS331::MED_RANGE);           // LOW_RANGE = 100g, MED_RANGE = 200g, HIGH_RANGE = 400g
  myLis.begin(LIS331::USE_I2C);             // Uses I2C rather than SPI
  Serial.println("STARTUP ROUTINE");    // Usually does not print. Serial comms is async and maybe gets clobbered in the soft device startup. 
///////////////////////////////////////////////////////////////////////////
  if (!lipo.begin())
  {
      // If communication fails, print an error message and loop forever.
      Serial.println("Error: Unable to communicate with BMS.");
      delay(5000);
  }
  if (lipo.itporFlag()) //write config parameters only if needed
    {
        Serial.println("BMS: Writing gauge config");

  //Advanced config settings are untested. Using defaults if commented out.
        //lipo.enterConfig();                     // To configure the values below, you must be in config mode. 
        lipo.setCapacity(BATTERY_CAPACITY);       // Set the battery capacity
        //lipo.setGPOUTPolarity(LOW);             // Set GPOUT to active-low
        //lipo.setGPOUTFunction(SOC_INT);         // Set GPOUT to SOC_INT mode
        //lipo.setSOCIDelta(PERCENTAGE_INTERVAL); // Set percentage change integer.
        //lipo.setDesignEnergy(BATTERY_CAPACITY * 3.7f);
        //lipo.setTerminateVoltage(TERMINATE_VOLTAGE);
        //lipo.setTaperRate(10 * BATTERY_CAPACITY / TAPER_CURRENT);
        //lipo.exitConfig(); // Exit config mode to save changes
    }
    else
    {
        Serial.println("BMS: Using existing gauge config");
    }

    // Use lipo.GPOUTPolarity to read from the chip and confirm the changes
//    if (lipo.GPOUTPolarity())
//      Serial.println("BMS GPOUT set to active-HIGH");
//    else
//      Serial.println("BMS GPOUT set to active-LOW");
//
//    Serial.println("BMS SOCI Delta: " + String(lipo.sociDelta()));
    
///////////////////////////////////////////////////////////////////////////

  Bluefruit.autoConnLed(true);
  Bluefruit.configPrphBandwidth(BANDWIDTH_MAX);
  //Bluefruit.configUuid128Count(15);
  Bluefruit.begin();
  Bluefruit.setTxPower(8);    //8 is max power (see bluefruit.h)
  //TxPower nRF52840: -40dBm, -20dBm, -16dBm, -12dBm, -8dBm, -4dBm, 0dBm, +2dBm, +3dBm, +4dBm, +5dBm, +6dBm, +7dBm and +8dBm.
  // Bluefruit.setInterval(6, 80);

  

  //Use Bluefruit.requestMtuExchange() to change packet size.

  Bluefruit.setName("Indigo Molar");      //(getMcuUniqueID()); // B5BBCD582C988315
  Bluefruit.Periph.setConnectCallback(connect_callback);
  Bluefruit.Periph.setDisconnectCallback(disconnect_callback);
  Bluefruit.Periph.setConnInterval(6, 12); // 7.5 - 15 ms (units of 1.25)    
  // Fast settings from 'throughput' example. Slow down as necessary when multiple peripherials are present? 
  
  // To be consistent OTA DFU should be added first if it exists
  bledfu.begin();

  // Configure and Start Device Information Service
  bledis.setManufacturer("HIMU Industries");
  bledis.setModel("9-DOF Hoof IMU");
  bledis.begin();

  // Configure and Start BLE Uart Service
  bleuart.begin();

//  myCharacteristic.setProperties(CHR_PROPS_NOTIFY);                 // Set characteristic to NOTIFY
  //myCharacteristic.setPermission(SECMODE_OPEN, SECMODE_NO_ACCESS);  // Read is open, Write is closed
//  myCharacteristic.setFixedLen(sizeof(myCharacteristic));           // <- THIS IS NECESSARY
//  myCharacteristic.begin();


  
  // Start BLE Battery Service
  blebas.begin();
  Serial.println("BATTERY STATUS:");
  printBatteryStats();
  
  // Set up and start advertising
  startAdv();

//////////////////////////////////////////////////////////////////////////
  
  if( !myISM.begin() )
  {
    Serial.println("6dof ISM Did not begin.");
    while(1);
  }
  
  // Reset the device to default settings. This if helpful is you're doing multiple
  // uploads testing different settings. 
  myISM.deviceReset();
  myISM.resetSensorHub();

  while( !myISM.getDeviceReset() ){ 
    yield();
  } 

  Serial.println("6dof ISM Reset.");
  delay(100);
  
  myISM.setDeviceConfig();
  myISM.setBlockDataUpdate();
  
///////////////////////////////////////////////////////////////////////////
// Configure the interrupt pin for the "Measurement Done" interrupt
    pinMode(mag_int_pin, INPUT);
    //attachInterrupt(digitalPinToInterrupt(mag_int_pin), interruptRoutine, RISING);

    if (myMag.begin() == false)
    {
        Serial.println("MAGNETOMETER did not respond - check your wiring. Freezing.");
        while (true);
    }

    myMag.softReset();

    Serial.print("TEMP: ");
    Serial.println(myMag.getTemperature());
    
    myMag.setFilterBandwidth(100);    //800, 400, 200 or 100.
    myMag.setContinuousModeFrequency(1000);   //1000, 200, 100, 50, 20, 10, 1 and 0.
    myMag.enableAutomaticSetReset();
    myMag.enableContinuousMode();
    myMag.enableInterrupt();
    // Set our interrupt flag, just in case we missed the rising edge
    newDataAvailable = true;
    
//////////////////////////////////////////////////////////////////////////////

  // Set the output data rate and precision of the accelerometer
  myISM.setAccelDataRate(ISM_XL_ODR_6667Hz);
  myISM.setAccelFullScale(ISM_8g); 

  // Set the output data rate and precision of the gyroscope
  myISM.setGyroDataRate(ISM_GY_ODR_6667Hz);
  myISM.setGyroFullScale(ISM_500dps); 

  // Turn on the accelerometer's filter and apply settings. 
  myISM.setAccelFilterLP2();
  myISM.setAccelSlopeFilter(ISM_LP_ODR_DIV_100);

  // Turn on the gyroscope's filter and apply settings. 
  myISM.setGyroFilterLP1();
  myISM.setGyroLP1Bandwidth(ISM_MEDIUM);

  // Set the accelerometer's status i.e. the data ready to interrupt one. 
  // Commented out just below is the function to send the data ready
  // to interrupt two. 

  myISM.setAccelStatustoInt1();
  
  // Uncommenting the function call below will change the interrupt to 
  // active LOW instead of HIGH.

  //myISM.setPinMode();

  // This function call will modify which "events" trigger an interrupt. No 
  // argument has been given, please refer to the datasheet for more 
  // information.

  // myISM.setIntNotification(uint8_t val);
}



void loop(){
//  if (digitalRead(GPOUT_PIN) == LOW)
//  {
//      printBatteryStats();    // SOC_INT occurred. Print battery stats.
//      blebas.notify(lipo.soc());      //State of charge: Current battery level as %.
//      
//  }

  
  while(!digitalRead(mag_int_pin))
  {yield;}    //wait for the int!

  myMag.clearMeasDoneInterrupt();                                        // Clear the MMC5983 interrupt
  uint32_t timenow = millis();                                           // uint32_t overflows at 49 days, uint16_t would overflow at 65.5 seconds.
  data.allData.millisecondsMSB = timenow >> 16;                      
  data.allData.millisecondsLSB = timenow & 0x0000FFFF;
  myMag.readFieldsXYZ(&rawValueX, &rawValueY, &rawValueZ);
  
  data.allData.magData.scaledX = rawValueX >> 2;
  data.allData.magData.scaledY = rawValueY >> 2;
  data.allData.magData.scaledZ = rawValueZ >> 2;

  if( (timenow - lasttime) > BAS_TIME_INTERVAL )
  {
    printBatteryStats();          // Print battery stats locally.
    blebas.notify(lipo.soc());    //State of charge: Current battery level as %.
    lasttime = timenow;
  }
              
  // Check if both gyroscope and accelerometer data is available.
  if( myISM.checkStatus() )
  {
    myISM.getRawAccel(&data.allData.accelData);                 // Low-g
    myISM.getRawGyro(&data.allData.gyroData);                   // Gyroscope
    myLis.readAxes(rawAccelX, rawAccelY, rawAccelZ);         // High-g
    data.allData.high_g_data.X = (uint16_t) rawAccelX;
    data.allData.high_g_data.Y = (uint16_t) rawAccelY;
    data.allData.high_g_data.Z = (uint16_t) rawAccelZ;
  }


//PRINT STATEMENTS.

  //myCharacteristic.notify(&data.buf, union_size);                 // Set characteristic message, and notify client

  size_t len = bleuart.write((const char *)&data.buf, union_size);
  Serial.print(len);
  Serial.print("\t");
  Serial.println(union_size);
  
    //Serial.write((const char *)&data.buf, union_size);

 
  for(int i=0;i < union_size>>1; i++)
    {
      Serial.print(data.buf[i]);    //mag data is supposed to be unsigned and will not look correct.
      Serial.print("\t");
    }
    Serial.println();
  
}



void startAdv(void)
{
  // Advertising packet
  Bluefruit.Advertising.addFlags(BLE_GAP_ADV_FLAGS_LE_ONLY_GENERAL_DISC_MODE);
  Bluefruit.Advertising.addTxPower();

  // Include bleuart 128-bit uuid
  Bluefruit.Advertising.addService(bleuart);

  // Secondary Scan Response packet (optional)
  // Since there is no room for 'Name' in Advertising packet
  Bluefruit.ScanResponse.addName();
  
  /* Start Advertising
   * - Enable auto advertising if disconnected
   * - Interval:  fast mode = 20 ms, slow mode = 152.5 ms
   * - Timeout for fast mode is 30 seconds
   * - Start(timeout) with timeout = 0 will advertise forever (until connected)
   * 
   * For recommended advertising interval
   * https://developer.apple.com/library/content/qa/qa1931/_index.html   
   */
  Bluefruit.Advertising.restartOnDisconnect(true);
  Bluefruit.Advertising.setInterval(32, 244);    // in unit of 0.625 ms (originally 32)
  Bluefruit.Advertising.setFastTimeout(30);      // number of seconds in fast mode
  Bluefruit.Advertising.start(0);                // 0 = Don't stop advertising after n seconds  
}

//////////////////////////////////////////////////////////////////

// callback invoked when central connects
void connect_callback(uint16_t conn_handle)
{
  // Get the reference to current connection
  BLEConnection* connection = Bluefruit.Connection(conn_handle);

  char central_name[32] = { 0 };
  connection->getPeerName(central_name, sizeof(central_name));

  Serial.print("Connected to ");
  Serial.println(central_name);
/////////////////////////////////////////////////////////////////
  // request PHY changed to 2MB
  // This doubles the physical layer speed, increasing packet speed, but doesnt change connection interval so throughput is not necessarily changed.
  //Serial.println("Request to change PHY");
  connection->requestPHY();

  // request to update data length
  Serial.println("Request to change Data Length");
  connection->requestDataLengthUpdate(); 
    
  // request mtu exchange
  // 247 is max packet size. adjust to actual sensor data size.
  Serial.println("Request to change MTU");
  connection->requestMtuExchange(100);    //(sizeof(myData) + 3)

  // request connection interval of 7.5 ms
  connection->requestConnectionParameter(6); // in unit of 1.25

  // delay a bit for all the request to complete
  delay(1000);
  
  // Serial.println(connection->getMtu());
  //Serial.print(Bluefruit.getMaxMtu(conn_handle));
}



/**
 * Callback invoked when a connection is dropped
 * @param conn_handle connection where this event happens
 * @param reason is a BLE_HCI_STATUS_CODE which can be found in ble_hci.h
 */
void disconnect_callback(uint16_t conn_handle, uint8_t reason)
{
  (void) conn_handle;
  (void) reason;

  Serial.println();
  Serial.print("Disconnected, reason = 0x"); Serial.println(reason, HEX);

  bleuart.flush();
}



void printBatteryStats()
{
    // Read battery stats from the BQ27441-G1A
    unsigned int soc = lipo.soc();                   // Read state-of-charge (%)
    unsigned int volts = lipo.voltage();             // Read battery voltage (mV)
    int current = lipo.current(AVG);                 // Read average current (mA)
    unsigned int fullCapacity = lipo.capacity(FULL); // Read full capacity (mAh)
    unsigned int capacity = lipo.capacity(REMAIN);   // Read remaining capacity (mAh)
    int power = lipo.power();                        // Read average power draw (mW)
    int health = lipo.soh();                         // Read state-of-health (%)

    // Assemble a string to print
    String toPrint = "[" + String(millis() / 1000) + "] ";
    toPrint += String(soc) + "% | ";
    toPrint += String(volts) + " mV | ";
    toPrint += String(current) + " mA | ";
    toPrint += String(capacity) + " / ";
    toPrint += String(fullCapacity) + " mAh | ";
    toPrint += String(power) + " mW | ";
    toPrint += String(health) + "%";

    //fast charging allowed
    if (lipo.chgFlag())
        toPrint += " CHG";

    //full charge detected
    if (lipo.fcFlag())
        toPrint += " FC";

    //battery is discharging
    if (lipo.dsgFlag())
        toPrint += " DSG";

    // Print the string
    Serial.println(toPrint);
}

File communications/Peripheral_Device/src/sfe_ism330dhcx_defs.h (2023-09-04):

//Accelerometer Full Scale
#define ISM_2g    0
#define ISM_16g   1
#define ISM_4g    2
#define ISM_8g    3

//Gyroscope Full Scale
#define ISM_125dps    2
#define ISM_250dps    0
#define ISM_500dps    4
#define ISM_1000dps   8
#define ISM_2000dps   12
#define ISM_4000dps   1

//Acceleromter Output Data Rate
#define ISM_XL_ODR_OFF     0
#define ISM_XL_ODR_12Hz5   1
#define ISM_XL_ODR_26Hz    2
#define ISM_XL_ODR_52Hz    3
#define ISM_XL_ODR_104Hz   4
#define ISM_XL_ODR_208Hz   5
#define ISM_XL_ODR_416Hz   6
#define ISM_XL_ODR_833Hz   7
#define ISM_XL_ODR_1666Hz  8
#define ISM_XL_ODR_3332Hz  9
#define ISM_XL_ODR_6667Hz  10
#define ISM_XL_ODR_1Hz6    11

//Gyroscope Output Data Rate
#define ISM_GY_ODR_OFF     0
#define ISM_GY_ODR_12Hz    1
#define ISM_GY_ODR_26Hz    2
#define ISM_GY_ODR_52Hz    3
#define ISM_GY_ODR_104Hz   4
#define ISM_GY_ODR_208Hz   5
#define ISM_GY_ODR_416Hz   6
#define ISM_GY_ODR_833Hz   7
#define ISM_GY_ODR_1666Hz  8
#define ISM_GY_ODR_3332Hz  9
#define ISM_GY_ODR_6667Hz  10

//Gyro Bandwidth set
#define ISM_ULTRA_LIGHT   0
#define ISM_VERY_LIGHT    1
#define ISM_LIGHT         2
#define ISM_MEDIUM        3
#define ISM_STRONG        4
#define ISM_VERY_STRONG   5
#define ISM_AGGRESSIVE    6
#define ISM_XTREME        7

// Gyro high performance filters												
#define ISM_HP_FILTER_NONE    0x00
#define ISM_HP_FILTER_16mHz   0x80
#define ISM_HP_FILTER_65mHz   0x81
#define ISM_HP_FILTER_260mHz  0x82
#define ISM_HP_FILTER_1Hz04   0x83

//Accel Regular Performance Filter Settings
#define ISM_HP_PATH_DISABLE_ON_OUT  0x00
#define ISM_SLOPE_ODR_DIV_4         0x10
#define ISM_HP_ODR_DIV_10           0x11
#define ISM_HP_ODR_DIV_20           0x12
#define ISM_HP_ODR_DIV_45           0x13
#define ISM_HP_ODR_DIV_100          0x14
#define ISM_HP_ODR_DIV_200          0x15
#define ISM_HP_ODR_DIV_400          0x16
#define ISM_HP_ODR_DIV_800          0x17
#define ISM_HP_REF_MD_ODR_DIV_10    0x31
#define ISM_HP_REF_MD_ODR_DIV_20    0x32
#define ISM_HP_REF_MD_ODR_DIV_45    0x33
#define ISM_HP_REF_MD_ODR_DIV_100   0x34
#define ISM_HP_REF_MD_ODR_DIV_200   0x35
#define ISM_HP_REF_MD_ODR_DIV_400   0x36
#define ISM_HP_REF_MD_ODR_DIV_800   0x37
#define ISM_LP_ODR_DIV_10           0x01
#define ISM_LP_ODR_DIV_20           0x02
#define ISM_LP_ODR_DIV_45           0x03
#define ISM_LP_ODR_DIV_100          0x04
#define ISM_LP_ODR_DIV_200          0x05
#define ISM_LP_ODR_DIV_400          0x06
#define ISM_LP_ODR_DIV_800          0x07

//FIFO Mode Settings
#define ISM_BYPASS_MODE           0x00
#define ISM_FIFO_MODE             0x01
#define ISM_STREAM_TO_FIFO_MODE   0x03
#define ISM_BYPASS_TO_STREAM_MODE 0x04
#define ISM_STREAM_MODE           0x06
#define ISM_BYPASS_TO_FIFO_MODE   0x07

//FIFO Accelerometer Batch Settings
#define ISM_XL_NOT_BATCHED       0x00
#define ISM_XL_BATCH_AT_12Hz5    0x01
#define ISM_XL_BATCH_AT_26Hz     0x02
#define ISM_XL_BATCH_AT_52Hz     0x03
#define ISM_XL_BATCH_AT_104Hz    0x04
#define ISM_XL_BATCH_AT_208Hz    0x05
#define ISM_XL_BATCH_AT_417Hz    0x06
#define ISM_XL_BATCH_AT_833Hz    0x07
#define ISM_XL_BATCH_AT_1667Hz   0x08
#define ISM_XL_BATCH_AT_3333Hz   0x09
#define ISM_XL_BATCH_AT_6667Hz   0x010
#define ISM_XL_BATCH_6Hz5        0x011

//FIFO Gyroscope Batch Settings
#define ISM_GY_NOT_BATCHED      0x00
#define ISM_GY_BATCH_AT_12Hz5    0x01
#define ISM_GY_BATCH_AT_26Hz     0x02
#define ISM_GY_BATCH_AT_52Hz     0x03
#define ISM_GY_BATCH_AT_104Hz    0x04
#define ISM_GY_BATCH_AT_208Hz    0x05
#define ISM_GY_BATCH_AT_417Hz    0x06
#define ISM_GY_BATCH_AT_833Hz    0x07
#define ISM_GY_BATCH_AT_1667Hz   0x08
#define ISM_GY_BATCH_AT_3333Hz   0x09
#define ISM_GY_BATCH_AT_6667Hz   0x010
#define ISM_GY_BATCH_6Hz5        0x011

//Decimation rate
#define ISM_NO_DECIMATION 0x00
#define ISM_DEC_1         0x01
#define ISM_DEC_8         0x02
#define ISM_DEC_32        0x03

//Interrupt pin notification settings.
#define ISM_ALL_INT_PULSED            0x00
#define ISM_BASE_LATCHED_EMB_PULSED   0x01
#define ISM_BASE_PULSED_EMB_LATCHED   0x02
#define ISM_ALL_INT_LATCHED           0x03

#define ISM_SH_ODR_104Hz 0x00
#define ISM_SH_ODR_52Hz  0x01
#define ISM_SH_ODR_26Hz  0x02
#define ISM_SH_ODR_13Hz  0x03

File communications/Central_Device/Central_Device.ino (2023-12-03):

/**************************************************************************
 * Author: Kyle Garcia, Kevin Brannan                                                    *
 *                                                                        *
 * Title: Central Device                                                  *
 * Description: Data Receiver using CLIENT Libraries for BLE Comms        *
 *                                                                        *
 * Purpose: To collect information from BLE Servers, which are the IMUs,  *
 * then output them into MATLAB for processing.                            *
 **************************************************************************/

/*>>>>>>>>>>>>>>>>>>>>>>>>>>>>> LIBRARIES <<<<<<<<<<<<<<<<<<<<<<<<<<<<<<<<*/

#include <Arduino.h>
#include <Wire.h>
#include <bluefruit.h>
//#include <Adafruit_LittleFS.h>
//#include <InternalFileSystem.h>

// BLE Services Instantiation
BLEDfu bledfu;
BLEClientDis bledis;
BLEClientUart bleuart;
BLEClientBas blebas;

// A struct that contains the peripheral info
typedef struct
{
  char name[16+1];
  uint16_t connection_handle;
  BLEClientUart bleuart; // Each prph needs its own bleuart client service
  BLEClientBas blebas;
  //bool PACKET_FULL;
  uint16_t counter;
  int16_t newPacket[30];    // Oversized for future expansion
} prph_info_t;

prph_info_t prphs[BLE_MAX_CONNECTION];
uint8_t connection_num = 0; // for blink pattern

void setup() {
  Serial.begin(115200);
  while(!Serial) delay(10); // for nrf5820 with native USB
  Bluefruit.configCentralBandwidth(BANDWIDTH_MAX);
  Bluefruit.begin(0, 1); // was 1, 1 // was 0, 4
  Bluefruit.setName("Central Denture"); // Set name of hub

//
//

  // initialize the peripheral pool, scan through and collect up to 20 BLE devices
  for (uint8_t index = 0; index < BLE_MAX_CONNECTION; index++)
  {
      // Invalidate all connetion handles
      prphs[index].connection_handle = BLE_CONN_HANDLE_INVALID;

      // All of the BLE Central UART Service
      prphs[index].bleuart.begin();
      prphs[index].blebas.setNotifyCallback(bas_notify_callback);
      prphs[index].blebas.begin();

      prphs[index].bleuart.setRxCallback(bleuart_rx_callback);
  }
      // Callbacks for Central
      Bluefruit.Central.setConnectCallback(connect_callback);
      Bluefruit.Central.setDisconnectCallback(disconnect_callback);
       /* Start Central Scanning
   * - Enable auto scan if disconnected
   * - Interval = 100 ms, window = 80 ms
   * - Filter only accept bleuart service in advertising
   * - Don't use active scan (used to retrieve the optional scan response adv packet)
   * - Start(0) = will scan forever since no timeout is given
   */
    Bluefruit.Scanner.setRxCallback(scan_callback);
    Bluefruit.Scanner.restartOnDisconnect(true);
    Bluefruit.Scanner.setInterval(24, 12); // had it as 24, 12 //Originally 160 for fast mode       // in units of 0.625 ms // 24, 12
    Bluefruit.Scanner.filterUuid(BLEUART_UUID_SERVICE);
    Bluefruit.Scanner.useActiveScan(false);       // Don't request scan response data
    Bluefruit.Scanner.start(0);                   // 0 = Don't stop scanning after n seconds
}

/**
 * Callback invoked when scanner picks up an advertising packet
 * @param report Structural advertising data
 */
void scan_callback(ble_gap_evt_adv_report_t* report)
{
  // Since we configure the scanner with filterUuid()
  if (Bluefruit.Scanner.checkReportForService(report, bleuart))
  {
    // Scan callback only invoked for device with bleuart service advertised  
    // Connect to the device with bleuart service in advertising packet
    Bluefruit.Central.connect(report);
  }
  else
  {
    Bluefruit.Scanner.resume();
  }
}

/*
 * Callback invoked when an connection is established
 * @param conn_handle
 */

void connect_callback(uint16_t conn_handle)
{
  // Find an available ID to use
  int id  = findConnHandle(BLE_CONN_HANDLE_INVALID);

  // Eeek: Exceeded the number of connections !!!
  if ( id < 0 ) return;
  
  prph_info_t* peer = &prphs[id];
  peer->connection_handle = conn_handle;
  
  Bluefruit.Connection(conn_handle)->getPeerName(peer->name, sizeof(peer->name)-1);

  Serial.print("Connected to ");
  Serial.println(peer->name);
  
  Serial.print("Discovering BLE UART service ... ");
  
  if (peer->blebas.discover(conn_handle))
  {
    Serial.println("THE BATTERY LEVEL IS: ");
    Serial.println(blebas.read());
    delay(2000);
  }
  else 
  {
    Serial.println("Battery Not discovered");
  }
  if(peer->blebas.enableNotify())
  {
    Serial.println("BAS Notify enabled.");
  }
  else
  {
    Serial.println("BAS Notify fail!");
  }

  if ( peer->bleuart.discover(conn_handle) )
  {
    Serial.println("Found it");
    Serial.println("Enabling TXD characteristic's CCCD notify bit");
    peer->bleuart.enableTXD();
    Serial.println("Continue scanning for more peripherals");
    Bluefruit.Scanner.start(0);

    Serial.println("Enter some text in the Serial Monitor to send it to all connected peripherals:");
  } else
  {
    Serial.println("Found ... NOTHING!");

    // disconnect since we couldn't find bleuart service
    Bluefruit.disconnect(conn_handle);
  }  

  connection_num++;
}

/**
 * Callback invoked when a connection is dropped
 * @param conn_handle
 * @param reason is a BLE_HCI_STATUS_CODE which can be found in ble_hci.h
 */
void disconnect_callback(uint16_t conn_handle, uint8_t reason)
{
  (void) conn_handle;
  (void) reason;

  connection_num--;

  // Mark the ID as invalid
  int id  = findConnHandle(conn_handle);

  // Non-existant connection, something went wrong, DBG !!!
  if ( id < 0 ) return;

  // Mark conn handle as invalid
  prphs[id].connection_handle = BLE_CONN_HANDLE_INVALID;

  Serial.print(prphs[id].name);
  Serial.println(" disconnected!");
}

/**
 * Callback invoked when BLE UART data is received
 * @param uart_svc Reference object to the service where the data 
 * arrived.
 */
void bleuart_rx_callback(BLEClientUart& uart_svc)
{
  // uart_svc is prphs[conn_handle].bleuart
  uint16_t conn_handle = uart_svc.connHandle();
  int id = findConnHandle(conn_handle);
  prph_info_t* peer = &prphs[id];

  // Read then forward to all peripherals
  if ( uart_svc.available() )
  {
    // default MTU with an extra byte for string terminator <- CHANGED.
    char buf[30];
    int16_t packetSize = sizeof(buf);
    int16_t bytes = uart_svc.read(buf, packetSize);
    int16_t sentPacketSize = packetSize >> 1;
    int16_t data[sentPacketSize];
    for (int k = 0; k < sentPacketSize; k++){
      data[k] = (buf[k+k]) | (buf[(k+k)+1]<<8);
    }

  if (data[0] == 9509) {
    // Print sender's name
    //Serial.printf("[From %s]: ", peer->name);
    data[0] = peer->connection_handle;
    for (int i = 0; i < sentPacketSize; i++){
      peer->newPacket[i] = data[i];
      Serial.print(peer->newPacket[i]);
      Serial.print('\t');
    }
    Serial.println();
  }
  }
}
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

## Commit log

2023-08-29 Create EAGLE-COMPONENTS
    This is where eagle parts or components will reside for use in the PCB
2023-08-30 Update and rename COM_TEAL_0829.ino to Testing_Peripheral_Teal.ino
    Renamed the prototyping device reprogrammed by Elena
2023-08-30 Added folders for .ino files so that they may run as is in Arduino IDE
2023-08-30 Renamed all the directories with lower case, and added a datasheets folder
2023-08-30 Added eagle part files for BMS and Sensors, added datasheets directory and some datasheets
2023-08-30 added MATLAB script that takes data from COM Port and creates a .csv file. However, there is currently no automatic way to select the COM PORT
2023-09-04 Added 9 DOF IMU Datasheet
2023-09-04 Added Arduino.h to allow usage in other IDEs
2023-09-05 added info update to sensors
2023-09-12 Updated Peripheral Device with Latest Code
2023-09-26 added BetterSerialMonitor
    [DataSample3.csv]
2023-09-26 added new data file and added updated presentation
    [data_09262023.csv]
2023-10-31 Added millis timestamp and adjusted packet size
2023-11-06 Added Version of External Shell, WIP
    Currently contains the BMS/Battery Slots
    [SDP_IMU_HOLDER v4.f3d]
2023-11-06 millisecond counter added to packet
2023-11-06 Added 5 Step Files for the IMU Shell
    Most of the files use a pin system, please print with 0.4 nozzle and very slow and high temps to ensure part strength and precision. More details later
    [BMS Battery Holder.step, Bottom Plate.step, IMU_Holder.step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]
2023-11-06 Added Printable Step Files Version 1
    [BMS Battery Holder.step, Bottom Plate.step, IMU_Holder.step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]
2023-11-07 BMS library implimented
2023-11-07 BMS settings adjusted. Working on an event trigger to NOTIFY battery level. to Central.
2023-11-07 Added notify callback for BMS
2023-11-21 finished BMS notify based on timer.
2023-12-02 Updated Serial Plotter and Confirmed Central Plotter
    The serial monitor was not printing on a separate line from the data, which caused live plotting errors, should be resolved. Also updated the senior plotter config file for the sensors.
    [Central_Device.ino]
2023-12-02 Added correct library for 3-Axis High G Accelerometer
    Removing old library, as it is not compatible with the hardware without changes to the library
2023-12-02 Cleaned communications folder
    [DataSample3.csv]
2023-12-03 Added libraries into sketch folder. Also implementing high g accelerometer into code.
2023-12-03 Fixed the extraneous 0 at the end of the data
    [Central_Device.ino]
2023-12-03 Changed Battery Notify Interval from 5s to 60s
2023-12-03 Added V2 IMU Shell Design
    Compared to V1, these are more printer-friendly and recommended to be printed in PETG. Additionally, there are fewer parts to print.
    [Accelerometer_Press_Plate.step, BMS Battery Holder.step, Bottom Plate.step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]
2023-12-03 Added csv from Live Demo, and changed BetterSerialMonitor Config
    [data_12032023.csv]
2023-12-08 Added Fusion 360 Model for IMU Assembly
2023-12-09 arduino code to test all parameter
